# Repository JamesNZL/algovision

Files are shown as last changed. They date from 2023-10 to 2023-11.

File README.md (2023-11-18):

<div align="center">
   
</div>

# algovision

<div align="center">
   <br>
   <div>
      <a href="https://github.com/JamesNZL/algovision/issues">
         
      </a>
      <a href="https://github.com/JamesNZL/algovision/pulls">
         
      </a>
      <!-- <a href="https://github.com/JamesNZL/algovision/actions/workflows/release.yml">
         <img src="https://img.shields.io/github/actions/workflow/status/jamesnzl/algovision/release.yml?branch=main" alt="GitHub workflow status">
      </a> -->
      <a href="https://github.com/JamesNZL/algovision/commits">
         
      </a>
   </div>
   <br>
</div>

A self-driven project to design an algorithm visualisation tool with a union of hardware and firmware.

## Project Documentation

> [!important]
> Visit the [GitHub Pages deployment](https://docs.jamesnzl.xyz/algovision) to view the documentation for this project.

## Software Used

| Package | Used for |
| --- | --- |
| Obsidian | The scratch pad for documentation and design. |
| Concepts | The rough sketches and ideation. |
| Visual Studio Code | The text editing and firmware development. |
| LTspice | The hardware simulation and verification. |
| Altium Designer | The schematic capture and PCB artwork. |
| SOLIDWORKS | The 3D models of components. |
| Figma | The iterative matrix mockups and topology design. |
| Adobe Illustrator  | The algovision logo. |

# Licence

The [`Karbon`](https://klim.co.nz/retail-fonts/karbon/) font family is licensed for perpetual use within this project under the terms of the [Klim Desktop Font Licence Agreement](https://klim.co.nz/licences/desktop-fonts/).

The hardware design files in this repository are licensed under the `CERN Open Hardware Licence Version 2 - Permissive`, and source code is licensed under `MIT`.

See [`LICENSE.md`](./LICENSE.md) for full details.

Learn more about [open-source hardware](https://www.oshwa.org/faq/).

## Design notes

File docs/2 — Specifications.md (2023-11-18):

#5e5ce6/projects 

# Specifications

> [!NOTE]  
> This document lists the specifications that the outcome must satisfy.

---

1. The outcome must be portable, and no larger than an iPad mini 6 ($195.43\,\text{mm} \times 134.75\,\text{mm}$, $12.88\,\text{mm}$ corner radius, [reference](https://developer.apple.com/accessories/Accessory-Design-Guidelines.pdf#page=284)).

2. The outcome must be reasonably priced—I don't mind putting a bit of money into it, and the focus is not on making something commercially viable—but it should be realistic.

3. The outcome must be aesthetically pleasing.

4. The outcome must be [[power]] efficient and [[Batteries|battery]] powered.

5. The outcome must be capable of an [[Auto-Shutdown|auto-sleep/shutdown]] if left unattended.

6. The outcome must be easily programmed using a [[USB Type-C Connectors|USB Type-C connector]].

7. The outcome must be effective towards its goal of aiding in the visualisation of different [[sorting]] and [[pathfinding]]/[[search]] [[algorithms]].

8. The outcome must be self-contained, and must not be reliant on any extraneous supplies/loads/test environments/etc.

9. The outcome must have [[Scopes/Interface/Operating Modes|operating modes]] to either single-step through an algorithm, or automatically execute at a configurable rate.

10. The outcome must have [[Scopes/Power/Power Indicator|power indicator]] LEDs to notify the user when the batteries have [[Scopes/Power/Battery Voltage Sensing|discharged too far]].

11. The outcome must include [[Scopes/Interface/Debug LEDs|debug]] pins/test points and LEDs to facilitate effective development and debugging.

12. The outcome should be easy to operate, with minimal [[Interface|end-user input]] required.

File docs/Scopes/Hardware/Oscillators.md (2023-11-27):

#5e5ce6/projects 

# Oscillators

I will need to select two oscillators in this project:

1. [[TLC5951DAP]] [[LED Drivers|LED Driver]] greyscale clock, and
2. [[STM32U575CIT6Q]] `HSE` clock.

## Greyscale Clock

I calculated in [[Minimum Data Frequency]] that my greyscale reference clock should be at least $5.16\,\text{MHz}$ for the full 12-bit resolution [[Pixel Brightness]] control.

I also know that the [[TLC5951DAP]] can accept a maximum greyscale clock frequency of $33\,\text{MHz}$, and, owing to the [[Auto Display Repeat]] functionality, I will aim to select a clock frequency nearer to the upper-end of this, for greater granularity/smooth persistence-of-vision in my LED pixel brightnesses.

I will select an oscillator by primarily considering cost, stock, temperature stability, accuracy, power consumption, and jitter, and just making sure that the selected oscillator has a frequency $5.2\,\text{MHz} \ll f_\text{osc} < 33\,\text{MHz}$.

Performing a parametric search on DigiKey, to filter for only part numbers that are:
1. surface mount,
2. in stock,
3. active product status, and
4. have a datasheet,
I narrow down the product selection from over 440 thousand to 171 thousand.

I see that I have an option between crystal-type oscillators and MEMS-type oscillators,

### Microcontroller `HSE` Clock

For my microcontroller `HSE` clock, I will simply re-use the same $32\,\text{MHz}$ oscillator that I selected for my greyscale clock above, for purposes of BOM consolidation. This selected oscillator is equally fit-for-purpose for this application, for the reasons discussed in [[Microcontroller#`HSE` Clock]].

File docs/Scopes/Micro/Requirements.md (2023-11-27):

#5e5ce6/projects 

# Requirements

## Peripherals

### RAM

To get a ball-park estimate, I will consider just my [[Frame Buffers]]—assuming that I have two rotating frame buffers for my [[Display]], this gives me a minimum of $8.7\,\text{kiB}$ of RAM required.

### Timers

I will need a timer for:

1. Row control [[Shift Registers]] timing
2. ~~Column control [[LED Drivers]] greyscale reference clock~~
	> I will actually provide this with a dedicated [[Oscillators]] to reduce the workload of my [[Microcontroller]], and reduce the routing of high-speed signal traces.

As per my [[Minimum Data Frequency]] calculations, I must clock my shift registers at least at $1260\,\text{Hz}$, or a period of $0.8\,\text{ms}$. This will be easily achievable with a 8- or 16-bit timer with a clock prescaler applied to the system clock.

### SPI

For my [[Display]], I must select a microcontroller that is capable of transferring serial data to my [[LED Drivers]] at the required [[Minimum Data Frequency]] of at least $f_\text{clk, SPI} > 18.2\,\text{MHz}$.

I note that this is separate from the microcontroller's operating frequency; as there is no inherent synchronisation between the [[Frame Buffers]] and the matrix timing constraints—as long as I can shift the data out from the read-only frame buffer in time with enough left-over instructions to slowly compute the contents of the write-only frame buffer, everything should be fine.

### GPIO

| Purpose | Pins Required | Remarks |
| --- | --- | --- |
| [[Display]] row control | 3 | Shift register clear, clock, serial input |
| [[Display]] column control | 8 | LED driver `GSSIN`, `DCSIN`, `GSSCK`, `GSLAT`, `DCSCK`, `~XBLNK`, `GSCK`, flags input |
| [[Debug LEDs]] | 4+ | Heartbeat LED, status, `TX`, `RX`—assuming a single GPIO per LED |
| [[User Pushbuttons]] | 1+ | |
| [[Brightness Control]] | 1+ | |

For my [[Display|display]] [[Shift Registers|shift register]] row control, I intend on bit-banging the serial output using a GPIO pin and a timer interrupt. For my [[LED Drivers|LED driver]] column control however, I intend on using a serial SPI peripheral to transfer the data, and a separate timer interrupt for the greyscale reference clock pin.

This gives a total minimum of 17 available GPIO pins.

### ADC

At minimum, I will need one channel for my [[Brightness Control]] knob, and another channel for my [[Current Sensing]] signal.

### USB-UART

I would prefer to have a microcontroller that can be directly [[Programming|programmed]] with a [[USB Type-C Connectors|USB-C]] connection, without requiring an external [[Scopes/Micro/USB to Serial|USB-to-serial]] chip.

This will require further research to see whether this would still allow a debugger to be attached, though.

### Watchdog Timer

I will need at least one [[Watchdog Timer]]. Preferably, this will be a window watchdog—I can then perhaps configure it to require a refresh within a window around my row-refresh timing, to help ensure that my display is being driven with correct timing.

### USB PD PHY

It would be desirable to have in-built [[USB Power Delivery]] [[USB-C Configuration Controller]] or [[USB Power Delivery Control Peripheral]], such that I do not require an external USB-C/PD controller IC.

### Connectivity

I would like to have the option to implement wireless Bluetooth Low Energy/WiFi [[Connectivity|connectivity]] in the future.

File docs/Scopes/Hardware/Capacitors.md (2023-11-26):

#5e5ce6/projects 

# Capacitors

I will approach my capacitor selection similarly as to that for my [[Resistors]]—I will use a DigiKey parametric search.

I know that the primary application in this project will be for decoupling capacitors, and not much filtering/analogue. Consequently, I expect that my requirements are fairly relaxed, as I do not require extreme tolerances/stability/accuracy.

I would also expect the operating profile to be fairly low-calibre, as I do not expect this board to be used in extreme temperatures or otherwise demanding environments. With that said however, I will likely still need to consider operating temperatures due to the power dissipation of the components on the board.

With this considerations in mind, I will primarily focus on Class II MLCC capacitors, and specifically `X7R` type MLCCs. Due to the nature of my application, I will need to carefully consider capacitance degradation with respect to the applied DC bias voltage. For any filters/oscillator load capacitances, I will look at Class I `C0G` or `NP0` capacitors for their constant DC voltage and temperature response.

Unlike my search for [[Resistors]] however, in this case I will place less direct emphasis on a specific family of devices, in order to facilitate more application-specific decisions.

Applying a basic search filter to only parts that are:
1. surface mount,
2. in stock,
3. available as Cut Tape,
4. active product status, and
5. have a datasheet,
I narrow down the product selection from over 800 thousand to 36 thousand.

Sorting by stock quantity in descending order, I see that the most stocked manufacturers are:
- Murata
- Samsung
- YAGEO
- KYOCERA AVX
- Walsin

I see that the YAGEO [Commodity Multilayer Ceramic Capacitor](https://www.digikey.co.nz/en/product-highlight/y/yageo/commodity-multilayer-ceramic-capacitors-cc-series) series includes `NP0`, `X7R`, `X5R`, and `Y5V` type capacitors, such that I may just be able to stay within this one family. For purely aesthetic reasons, I also note that these YAGEO capacitors are the only black/grey devices compared to the typical brown/orange of the other manufacturers, which may look better on my black [[PCB]], and also means that I can have all my resistors/capacitors from one manufacturer.

Looking at Samsung's line of [MLCCs](https://www.digikey.co.nz/en/product-highlight/s/samsung-electromech/multi-layer-ceramic-capacitors), I see that this series only includes Class II type capacitors, and no Class I offerings—unlike the YAGEO series—but *does* include capacitances up to $200\,\micro\text{F}$, unlike the maximum capacitance of $100\,\micro\,\text{F}$ from YAGEO—but I do not expect this to be a problem as I do not expect to need capacitances this high (at least from an MLCC).

> [!success] Preferred Series
> I will use devices from the YAGEO [`CC`](https://www.yageo.com/en/Product/Index/mlcc) general purpose multi-layer ceramic capacitor series.

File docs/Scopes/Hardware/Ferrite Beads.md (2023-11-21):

#5e5ce6/projects 

# Ferrite Beads

As I have not used ferrite beads before, I want to first understand how to use them properly & select an appropriate part.

## Theoretical Analysis

I will begin by using [[LTspice]] to analyse an equivalent model.

![[Pasted image 20231120171100.png]]

I see that the ferrite bead acts as type of band-reject filter, where it attenuates high-frequency signals until the reactance of the parallel capacitor dominates and begins to act as a short circuit.

### Impedance Transfer Function

I will first derive the transfer function for the impedance of the equivalent model in the $s$ domain, to help myself visualise the frequency response of the ferrite bead.

#### Analytical

![[Pasted image 20231120173120.png]]

Taking the circuit into the Laplace domain, I see that I simply have three impedances in parallel, in series with $R_\text{s}$. The equivalent impedance is therefore derived as (assuming steady-state, ie zero initial conditions)
$$
\begin{align}
Z & = R_\text{s} + \left(\frac{1}{sC_\text{par}} \parallel sL_\text{bead} \parallel R_\text{AC}\right) \\[0.75em]
 & = R_\text{s} + \left( \frac{1}{sC_\text{par} + \frac{1}{sL_\text{bead}} + \frac{1}{R_\text{AC}} }\right) \\[0.75em]
 & = R_\text{s} + \left( \frac{sL_\text{bead}R_\text{AC}}{ s^2C_\text{par}L_\text{bead}R_\text{AC} + R_\text{AC} + sL_\text{bead} } \right) \\[0.75em]
 & = R_\text{s} + \frac{sL_\text{bead}R_\text{AC}}{s^2\left(C_\text{par}L_\text{bead}R_\text{AC}\right) + sL_\text{bead} + R_\text{AC}}
\end{align}
$$

Letting $s=j\omega$, I find
$$
\begin{align}
Z &= R_\text{s} + \frac{j\omega L_\text{bead}R_\text{AC}}{j^2\omega^2\left(C_\text{par}L_\text{bead}R_\text{AC}\right) + j\omega L_\text{bead} + R_\text{AC}} \\[0.75em]
&= R_\text{s}+\frac{j\omega L_\text{bead}R_\text{AC}}{-\omega^2\left(C_\text{par}L_\text{bead}R_\text{AC}\right) + j\omega L_\text{bead} + R_\text{AC}} \\[0.75em]
&= R_\text{s} + \frac{j\omega L_\text{bead}R_\text{AC}}{\left(R_\text{AC} - \omega^2C_\text{par}L_\text{bead}R_\text{AC}\right) + j\left(\omega L_\text{bead}\right)}\\[0.75em]
\end{align}
$$

Let $D$ be the denominator term, that is
$$
D = \left(R_\text{AC} - \omega^2C_\text{par}L_\text{bead}R_\text{AC}\right) + j\left(\omega L_\text{bead}\right)

$$

Combining the two terms into a single fraction, I have
$$
\begin{align}
Z &= \frac{R_\text{s}D}{D} + \frac{j\left(\omega L_\text{bead}R_\text{AC}\right)}{D}\\[0.75em]
&= \frac{R_\text{s}D + j\left(\omega L_\text{bead}R_\text{AC}\right)}{D} \\[0.75em]
&= \frac{R_\text{s}D + j\left(\omega L_\text{bead}R_\text{AC}\right)}{\left(R_\text{AC} - \omega^2C_\text{par}L_\text{bead}R_\text{AC}\right) + j\left(\omega L_\text{bead}\right)} \\[0.75em]
\end{align}
$$

Multiplying by the conjugate of the denominator $D$, ie $\overline{D}$, I have
$$
\begin{align}
Z &= \frac{R_\text{s}D + j\left(\omega L_\text{bead}R_\text{AC}\right) }{\left(R_\text{AC} - \omega^2C_\text{par}L_\text{bead}R_\text{AC}\right) + j\left(\omega L_\text{bead}\right)} \times \frac{\left(R_\text{AC} - \omega^2C_\text{par}L_\text{bead}R_\text{AC}\right) - j\left(\omega L_\text{bead}\right)}{\left(R_\text{AC} - \omega^2C_\text{par}L_\text{bead}R_\text{AC}\right) - j\left(\omega L_\text{bead}\right)}\\[0.75em]
&= \frac{\Bigl(R_\text{s}D + j\left(\omega L_\text{bead}R_\text{AC}\right) \Bigr) \Bigl(\left(R_\text{AC} - \omega^2C_\text{par}L_\text{bead}R_\text{AC}\right) - j\left(\omega L_\text{bead}\right)\Bigr)}{\left(R_\text{AC} - \omega^2C_\text{par}L_\text{bead}R_\text{AC}\right)^2 - j^2\left(\omega L_\text{bead}\right)^2} \\[0.75em]
&= \frac{   \Bigl(R_\text{s}R_\text{AC}D-\omega^2C_\text{par}L_\text{bead}R_\text{s}R_\text{AC}D-j\left(\omega L_\text{bead}R_\text{s}D\right)\Bigr)    +    \Bigl( j\left(\omega L_\text{bead}R_\text{AC}^2\right) - j\left( \omega^3C_\text{par}L_\text{bead}^2R_\text{AC}^2 \right)  - j^2\left( \omega^2L_\text{bead}^2R_\text{AC} \right)  \Bigr)     }{\left(R_\text{AC}^2 - 2\omega^2C_\text{par}L_\text{bead}R_\text{AC}^2+\omega^4C_\text{par}^2L_\text{bead}^2R_\text{AC}^2\right) + \left(\omega^2 L_\text{bead}^2\right)} \\[0.75em]
&= \frac{   R_\text{s}R_\text{AC}D-\omega^2C_\text{par}L_\text{bead}R_\text{s}R_\text{AC}D-j\left(\omega L_\text{bead}R_\text{s}D\right)    +    j\left(\omega L_\text{bead}R_\text{AC}^2\right) - j\left( \omega^3C_\text{par}L_\text{bead}^2R_\text{AC}^2 \right)  + \left( \omega^2L_\text{bead}^2R_\text{AC} \right)  }{\left(R_\text{AC}^2 - 2\omega^2C_\text{par}L_\text{bead}R_\text{AC}^2+\omega^4C_\text{par}^2L_\text{bead}^2R_\text{AC}^2\right) + \left(\omega^2 L_\text{bead}^2\right)} \\[0.75em]
&= \frac{  \Bigl(  \omega^2L_\text{bead}^2R_\text{AC} + R_\text{s}R_\text{AC}D-\omega^2C_\text{par}L_\text{bead}R_\text{s}R_\text{AC}D    \Bigr)    +   j\Bigl(       \omega L_\text{bead}R_\text{AC}^2  -\omega L_\text{bead}R_\text{s}D     -\omega^3C_\text{par}L_\text{bead}^2R_\text{AC}^2  \Bigr)   }{    \omega^4C_\text{par}^2L_\text{bead}^2R_\text{AC}^2 + \omega^2 L_\text{bead}^2 + R_\text{AC}^2 - 2\omega^2C_\text{par}L_\text{bead}R_\text{AC}^2    }
\end{align}
$$

Substituting $D$ back in, I get
$$
\begin{align}

Z &= \frac{  \Bigl(  \omega^2L_\text{bead}^2R_\text{AC} + R_\text{s}R_\text{AC}\Bigl(\left(R_\text{AC}-\omega^2C_\text{par}L_\text{bead}R_\text{AC}\right)+j\left(\omega L_\text{bead}\right)\Bigr)-\omega^2C_\text{par}L_\text{bead}R_\text{s}R_\text{AC}\Bigl(\left(R_\text{AC}-\omega^2C_\text{par}L_\text{bead}R_\text{AC}\right)+j\left(\omega L_\text{bead}\right)\Bigr)    \Bigr)    +   j\Bigl(       \omega L_\text{bead}R_\text{AC}^2  -\omega L_\text{bead}R_\text{s}\Bigl(\left(R_\text{AC}-\omega^2C_\text{par}L_\text{bead}R_\text{AC}\right)+j\left(\omega L_\text{bead}\right)\Bigr)     -\omega^3C_\text{par}L_\text{bead}^2R_\text{AC}^2  \Bigr)   }{    \omega^4C_\text{par}^2L_\text{bead}^2R_\text{AC}^2 + \omega^2 L_\text{bead}^2 + R_\text{AC}^2 - 2\omega^2C_\text{par}L_\text{bead}R_\text{AC}^2    } \\[0.75em]

&= \frac{  \Bigl(  \omega^2L_\text{bead}^2R_\text{AC} + R_\text{s}R_\text{AC}^2-\omega^2C_\text{par}L_\text{bead}R_\text{s}R_\text{AC}^2+j\left(\omega L_\text{bead}R_\text{s}R_\text{AC}\right)-\omega^2C_\text{par}L_\text{bead}R_\text{s}R_\text{AC}^2 + \omega^4C_\text{par}^2L_\text{bead}^2R_\text{s}R_\text{AC}^2-j\left(\omega^3C_\text{par} L_\text{bead}^2R_\text{s}R_\text{AC}\right)  \Bigr)  +   j\Bigl(       \omega L_\text{bead}R_\text{AC}^2  -\omega L_\text{bead}R_\text{s}      R_\text{AC}+\omega^3C_\text{par}L_\text{bead}^2R_\text{s}R_\text{AC}-j\left(\omega^2 L_\text{bead}^2R_\text{s}\right)     -\omega^3C_\text{par}L_\text{bead}^2R_\text{AC}^2  \Bigr)   }{    \omega^4C_\text{par}^2L_\text{bead}^2R_\text{AC}^2 + \omega^2 L_\text{bead}^2 + R_\text{AC}^2 - 2\omega^2C_\text{par}L_\text{bead}R_\text{AC}^2    } \\[0.75em]

&= \frac{  \Bigl(  \omega^2L_\text{bead}^2R_\text{AC} + R_\text{s}R_\text{AC}^2-\omega^2C_\text{par}L_\text{bead}R_\text{s}R_\text{AC}^2-\omega^2C_\text{par}L_\text{bead}R_\text{s}R_\text{AC}^2 + \omega^4C_\text{par}^2L_\text{bead}^2R_\text{s}R_\text{AC}^2  \Bigr) +   j\Bigl(       \omega L_\text{bead}R_\text{AC}^2 +\omega L_\text{bead}R_\text{s}R_\text{AC} -\omega L_\text{bead}R_\text{s}      R_\text{AC}+\omega^3C_\text{par}L_\text{bead}^2R_\text{s}R_\text{AC}  - \omega^3C_\text{par} L_\text{bead}^2R_\text{s}R_\text{AC}   -\omega^3C_\text{par}L_\text{bead}^2R_\text{AC}^2  \Bigr)  -j^2\left(\omega^2 L_\text{bead}^2R_\text{s}\right) }{    \omega^4C_\text{par}^2L_\text{bead}^2R_\text{AC}^2 + \omega^2 L_\text{bead}^2 + R_\text{AC}^2 - 2\omega^2C_\text{par}L_\text{bead}R_\text{AC}^2    } \\[0.75em]

&= \frac{  \Bigl(  \omega^2L_\text{bead}^2R_\text{AC} +\omega^2 L_\text{bead}^2R_\text{s} + R_\text{s}R_\text{AC}^2-\omega^2C_\text{par}L_\text{bead}R_\text{s}R_\text{AC}^2-\omega^2C_\text{par}L_\text{bead}R_\text{s}R_\text{AC}^2 + \omega^4C_\text{par}^2L_\text{bead}^2R_\text{s}R_\text{AC}^2  \Bigr) +   j\Bigl(       \omega L_\text{bead}R_\text{AC}^2 +\omega L_\text{bead}R_\text{s}R_\text{AC} -\omega L_\text{bead}R_\text{s}      R_\text{AC}+\omega^3C_\text{par}L_\text{bead}^2R_\text{s}R_\text{AC}  - \omega^3C_\text{par} L_\text{bead}^2R_\text{s}R_\text{AC}   -\omega^3C_\text{par}L_\text{bead}^2R_\text{AC}^2  \Bigr)   }{    \omega^4C_\text{par}^2L_\text{bead}^2R_\text{AC}^2 + \omega^2 L_\text{bead}^2  + R_\text{AC}^2 - 2\omega^2C_\text{par}L_\text{bead}R_\text{AC}^2    }

\end{align}
$$

Collecting like terms and simplifying, I have
$$
\begin{align}

Z &= \frac{  \Bigl(  \omega^4C_\text{par}^2L_\text{bead}^2R_\text{s}R_\text{AC}^2  + \omega^2L_\text{bead}^2R_\text{AC} +\omega^2 L_\text{bead}^2R_\text{s} + R_\text{s}R_\text{AC}^2-2\omega^2C_\text{par}L_\text{bead}R_\text{s}R_\text{AC}^2  \Bigr) +   j\Bigl(       \omega L_\text{bead}R_\text{AC}^2  -\omega^3C_\text{par}L_\text{bead}^2R_\text{AC}^2  \Bigr)   }{    \omega^4C_\text{par}^2L_\text{bead}^2R_\text{AC}^2 + \omega^2 L_\text{bead}^2 + R_\text{AC}^2 - 2\omega^2C_\text{par}L_\text{bead}R_\text{AC}^2    } \\[0.75em]

&= \frac{  \omega^4\left(C_\text{par}^2L_\text{bead}^2R_\text{s}R_\text{AC}^2\right)  + \omega^2\Bigl(L_\text{bead}^2\left(R_\text{AC} + R_\text{s}\right) - 2C_\text{par}L_\text{bead}R_\text{s}R_\text{AC}^2 \Bigr) + R_\text{s}R_\text{AC}^2    }{    \omega^4\left(C_\text{par}^2L_\text{bead}^2R_\text{AC}^2\right) + \omega^2\left( L_\text{bead}^2 - 2C_\text{par}L_\text{bead}R_\text{AC}^2 \right)   + R_\text{AC}^2   }  + \frac{ j\Bigl(       \omega L_\text{bead}R_\text{AC}^2  -\omega^3C_\text{par}L_\text{bead}^2R_\text{AC}^2  \Bigr) }{    \omega^4\left(C_\text{par}^2L_\text{bead}^2R_\text{AC}^2\right) + \omega^2\left( L_\text{bead}^2 - 2C_\text{par}L_\text{bead}R_\text{AC}^2 \right)   + R_\text{AC}^2   } \\[0.75em]

\end{align}
$$

![[Pasted image 20231121153742.png]]

Figure 2 of Analog Dialogue 50-02

Plotting the magnitude response in [Desmos](https://www.desmos.com/calculator/2eojibsjul), I see a plot that is very similar to `Figure 2` of [Analog Dialogue 50-02](https://www.analog.com/media/en/analog-dialogue/volume-50/number-1/articles/ferrite-beads-demystified.pdf), which is quite encouraging. I do see that although exact values are wrong (the $y$-axis value is off by *many* orders of magnitude), the general shape of the response is correct. Interestingly, if I reduce the order of the $-\omega^3$ term in the imaginary term to $-\omega^2$, the plot becomes *much* closer to the 'expected' value, as seen in the screenshot below.

![[Pasted image 20231121153827.png]]

I am not fully certain whether this is an algebraic error in my working, or what else it may be—but I do not think it is valuable to spend too much time on this topic.

> [!summary]
> I see in this plot (where the $x$-axis is frequency, in $\text{MHz}$) that the ferrite bead presents a very low impedance at low frequencies, whilst the inductive reactance dominates. As the frequency increases, I see a resonant peak where the $R_\text{AC}$ resistive component dominates, where the ferrite bead impedance increases significantly—which would lead to a larger voltage drop and power dissipated across the ferrite bead as heat energy. As the frequency continues to increase further however, the capacitive reactance dominates, such that the ferrite bead returns to presenting a low impedance.
> 
> Again, I see the band-reject characteristic of the ferrite bead.

#### MATLAB

```matlab
%%% FerriteImpedance.m
% A MATLAB script to model the impedance response of a ferrite bead.
%
% Author: James Bao

%% Sanitise Workspace
clear;
close all;
clc;

fprintf("FerriteBead.m\n\n");

%% Model Parameters

% Series Resistance
Rs = 0.3;

% Parasitic Capacitance
Cpar = 1.678e-12;

% Bead Inductance
Lbead = 1.208e-6;

% AC Resistance
Rac = 1.082e3;

%% Transfer Function

X_Cpar = tf(1, [Cpar 0]);
X_Lbead = tf([Lbead 0], 1);

Z = Rs + (1 / ((1/X_Cpar) + (1/X_Lbead) + (1/Rac)));

%% Plot Frequency Response

[mag, phase, w] = bode(Z, {0.1e6, 100e9});

w = w / (2 * pi * 1e6); % Convert w to f

semilogx(w, squeeze(mag));

xlabel('Frequency (MHz)', 'FontSize', 24);
ylabel('Impedance (Ohms)', 'FontSize', 24);
title('Impedance Response of Ferrite Bead Model', 'FontSize', 28);
```

![[Pasted image 20231121153407.png]]

Using [[MATLAB]] to plot the impedance response of my ferrite bead model with respect to frequency in order to validate my [[Ferrite Beads#Analytical|analytical]] working, I see that I reproduce the exact plot seen in the [Analog Dialogue 50-02](https://www.analog.com/media/en/analog-dialogue/volume-50/number-1/articles/ferrite-beads-demystified.pdf) article, and very similar to my Desmos plots.

### Frequency Response

#### Inductance

![[Pasted image 20231120171814.png]]

![[Pasted image 20231121014847.png]]

I see that increasing the inductance will pull the crossover frequency lower, whilst decreasing it will push it higher.

#### Capacitance

![[Pasted image 20231121014944.png]]

![[Pasted image 20231121014954.png]]

I see identical behaviour when changing the capacitance; the crossover frequency is inversely proportional to the parasitic capacitance $C_\text{par}$.

#### Resistance

![[Pasted image 20231121015122.png]]

![[Pasted image 20231121015132.png]]

Finally, I see that the AC loss resistance $R_\text{AC}$ does not have an effect on the crossover frequency, but does affect the amount of attenuation within the rejection band. This is as I would expect, as I would expect the crossover frequency to be dependent only on the reactive elements—whilst $R_\text{AC}$ captures the impedance presented to signals within the reject-band—and consequently the voltage drop & power dissipated.

![[Pasted image 20231121015443.png]]

![[Pasted image 20231121015458.png]]

Finally, I see a similar scaling behaviour when changing the series resistor $R_\text{s}$, but this is applied to the entire response, rather than just within the rejection band. This is again as I would expect, as this series resistor cannot be reduced by a parallel reactive element; it always contributes to the total impedance regardless of frequency.

### $LC$ Filter

#### Undamped

![[Pasted image 20231121132001.png]]

Modelling a simple $LC$ filter network in [[LTspice]] with a somewhat arbitrarily selected ferrite bead connected to my [[Microcontroller#Decoupling]] capacitors, I see a frequency response with a significant resonant peak at $\approx 47\,\text{kHz}$. This immediately tells me to expect a significant overshoot/ringing when looking at the time-domain step response of this filter, such as if there were to be some switching noise at the input.

![[Pasted image 20231121131701.png]]

![[Pasted image 20231121132933.png]]

Adjusting the source to model some (very arbitrary, and very exaggerated) switching noise and performing a transient analysis, I see exactly that ringing at the output of my filter.

Simplifying the ferrite bead to be a pure inductor of reactance $sL$, I can derive the transfer function of the filter to be a simple impedance divider with gain
$$
\begin{align}
G=\frac{V_\text{o}}{V_\text{s}}&=\frac{\frac{1}{sC}}{\frac{1}{sC}+sL}\\[0.75em]
&= \frac{1}{1+s^sLC}
\end{align}
$$

Considering the general form of a second-order transfer function
$$
G(s)=\frac{\omega_\text{n}^2}{s^2+2\zeta\omega_\text{n}s+\omega_\text{n}^2}=\frac{1}{1+(\frac{2\zeta}{\omega_\text{n}})s+(\frac{1}{\omega_\text{n}^2})s^2}
$$
I immediately see that I have a system with a natural frequency $w_\text{n}$ where
$$
\omega_\text{n}=\sqrt{\frac{1}{LC}}
$$
and a damping ratio $\zeta$
$$
\zeta=0
$$

This tells me that this models an undamped system, which helps to explain why I see so much oscillation. Of course, I see that the real system is, in fact, damped, but I still see value in this idealised understanding. As explained in the Analog Dialogue article, this is because the resistive component $R_\text{AC}$ does not become significant until a certain frequency, below which the ferrite bead does indeed behave as an ideal inductor.

This also tells me that the resonant frequency occurs at the natural frequency $\omega_\text{n}$, that is
$$
\begin{align}
\omega &= 2\pi f \\[0.75em]
f_\text{resonance} &= \frac{\sqrt{\frac{1}{LC}}}{2\pi}
\end{align}
$$
Applying this to my model, I calculate a resonant frequency $f_\text{resonance}=43\,\text{kHz}$—which is very close to the observed resonant frequency in my simulations. I would indeed expect a slight deviation due to the inaccuracies of my idealised model.

#### Damped

I know from control theory that, in order to reduce the magnitude of the resonant peak in the frequency domain, I must increase the damping ratio $\zeta$. I can do this by inserting an additional resistive element to dissipate energy, which I will add in series with the inductor.

This gives me a new gain $G'$
$$
\begin{align}
G'&=\frac{\frac{1}{sC}}{\frac{1}{sC}+\left(sL+R\right)} \\[0.75em]
&=\frac{1}{1+s^2LC+sCR}
\end{align}
$$

I see that I now have a damping ratio given by
$$
\begin{align}
\frac{2\zeta}{\omega_\text{n}}&=CR\\[0.75em]
\zeta &= \frac{CR\sqrt{\frac{1}{LC}}}{2}
\end{align}
$$
such that
$$
\zeta \propto R
$$

Therefore, for my original circuit with parameters
$$
\begin{align}
L &= 12.4\,\micro\text{H} \\[0.75em]
C &= 1.1\,\micro\text{F} \\[0.75em]
\end{align}
$$
and a desired damping ratio
$$
\zeta = 0.7
$$
I compute a necessary resistance
$$
\begin{align}
R &= \frac{2\zeta}{C\sqrt{\frac{1}{LC}}} \\[0.75em]
& = 4.7\,\Omega
\end{align}
$$

![[Pasted image 20231121174348.png]]

![[Pasted image 20231121174420.png]]

Simulating the response of this damped $RLC$ filter in [[LTspice]], I indeed see that the resonant peak and ringing has been eliminated, and the overshoot significantly reduced. Great!

#### Cut-Off Frequency

I do however still see that the switching noise is still present—this tells me that the roll-off frequency of my filter is too high, and is not attenuating the frequencies of interest. I know that my arbitrary, artificial switching pulse has an on-time of $100\,\micro\text{s}$ with edges of $10\,\text{ns}$. I will first try to filter out the fundamental frequency of
$$
\begin{align}
f_\text{fundamental} &= \frac{1}{2\times 100\,\micro\text{s}} \\[0.75em]
& = 5\,\text{kHz}
\end{align}
$$

I will therefore try to place my new roll-off frequency $f_\text{roll-off}'$ one decade lower than this, that is
$$
\begin{align}
f_\text{roll-off}' = f_\text{resonance} & = \frac{\sqrt{\frac{1}{LC'}}}{2\pi} \\[0.75em]
& =1\,\text{kHz} 
\end{align}
$$
Assuming a fixed inductor value, I will derive an expression for the new capacitance $C'$ as
$$
\begin{align}
C'&= \frac{1}{L\left(2\pi f_\text{roll-off}'\right)^2} \\[0.75em]
& = 2.04\,\text{mF}
\end{align}
$$
and a new damping resistor
$$
R'=109\,\text{m}\Omega
$$

Although these component values (ie $C'$) are not necessarily realistic (stemming from the arbitrary simulation setup), I am mostly interested in learning the process and developing an intuition around such resonant systems, and particularly the importance of damping elements—as I have not really had to deal with this before.

![[Pasted image 20231121174703.png]]

![[Pasted image 20231121174609.png]]

I see that these new $C'$ and $R'$ values do indeed pull the roll-off frequency to the left, and lead to an *much* cleaner transient response.

#### Conclusions

> [!summary]
> From this exploration, I have learnt:
> - The $LC$ filter formed with a ferrite bead and capacitor produces a low-pass characteristic
> - Without sufficient damping, the filter can exhibit a resonant peak and cause significant ringing
> - The cut-off frequency must be carefully chosen to actually attenuate the high-frequency noise of interest, where the cut-off frequency is dependent on the ferrite bead

![[Pasted image 20231121191229.png]]

I see that, if I choose to implement a ferrite bead in my design, I should make sure to fit a DNP zero-ohm jumper across the ferrite bead (and potentially the damping resistor, depending on its magnitude), in case I find that it actually negatively impacts the circuit. This will produce a simple first-order $RC$ low-pass filter with a reduced $-20\,\text{dB/dec}$ roll-off, but no risk of resonance.

## Implementation

### References

- [Ferrite Beads Demystified | Analog Devices](https://www.analog.com/en/analog-dialogue/articles/ferrite-beads-demystified.html)
- [How Do Ferrite Beads Work and How Do You Choose the Right One? | PCB Design Blog | Altium](https://resources.altium.com/p/how-do-ferrite-beads-work-and-how-do-you-choose-right-one)
- [Everything You Need to Know About Ferrite Beads | Altium](https://resources.altium.com/p/everything-you-need-to-know-about-ferrite-beads)

> [!note]
> A *great* video about using an $LC$ filter network on an analogue supply pin—[Shall We Use a Ferrite Bead in Power Rail or Not? | Explained by Eric Bogatin - YouTube](https://www.youtube.com/watch?v=HaLMjVkKYMw)

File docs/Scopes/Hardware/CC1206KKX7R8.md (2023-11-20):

#5e5ce6/projects 

# `CC1206KKX7R8`

> [!success] Preferred Series
> I will use devices from the YAGEO [`CC`](https://www.yageo.com/en/Product/Index/mlcc) general purpose multi-layer ceramic capacitor series.
> 
> Refer to [[Capacitors]] for full details.

| Part Number | `CC1206KKX7R8` |
| --- | --- |
| Image |  |
| Supplier Link  | [DigiKey](https://www.digikey.co.nz/short/997dt5n8) |
| Datasheet | [Datasheet](https://www.yageo.com/upload/media/product/productsearch/datasheet/mlcc/UPY-GPHC_X7R_6.3V-to-250V_23.pdf) |
| Terminals | 2 |
| Voltage Rating | $25\,\text{V}$ |
| Tolerance | $\pm 10\%$ |
| Type | `X7R` |
| Package | `1206` |

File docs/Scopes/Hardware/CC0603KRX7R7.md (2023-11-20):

#5e5ce6/projects 

# `CC0603KRX7R7`

> [!success] Preferred Series
> I will use devices from the YAGEO [`CC`](https://www.yageo.com/en/Product/Index/mlcc) general purpose multi-layer ceramic capacitor series.
> 
> Refer to [[Capacitors]] for full details.

| Part Number | `CC0603KRX7R7` |
| --- | --- |
| Image |  |
| Supplier Link  | [DigiKey](https://www.digikey.co.nz/short/997dt5n8) |
| Datasheet | [Datasheet](https://www.yageo.com/upload/media/product/productsearch/datasheet/mlcc/UPY-GPHC_X7R_6.3V-to-250V_23.pdf) |
| Terminals | 2 |
| Voltage Rating | $16\,\text{V}$ | 
| Tolerance | $\pm 10\%$
| Type | `X7R` |
| Package | `0603` |

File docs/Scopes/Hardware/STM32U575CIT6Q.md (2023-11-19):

#5e5ce6/projects 

# `STM32U575CIT6Q`

> [!success] Selected Device
> Following a thorough selection process as documented in [[STM32#Product Selector]], I have decided to proceed with the [`STM32U575CIT6Q`](https://www.digikey.co.nz/en/products/detail/stmicroelectronics/STM32U575CIT6Q/18085454).
> 
> Refer to [[STM32]] for full details.

| Part Number | `STM32U575CIT6Q` |
| --- | --- |
| Image |  |
| Supplier Link | [DigiKey](https://www.digikey.co.nz/en/products/detail/stmicroelectronics/STM32U575CIT6Q/18085454) |
| Datasheet | [Datasheet](https://www.st.com/resource/en/datasheet/stm32u575ag.pdf) |
| Package | `48-LQFP` |
| Pin Pitch | $0.5\,\text{mm}$ |
| Processor | Cortex-M33 |
| Voltage | $1.71\sim3.6\,\text{V}$ |
| Operating Frequency | $160\,\text{MHz}$ |
| Core Width | 32-bit |
| I/O Pins | 33 |
| Flash | $2048\,\text{kiB}$ |
| RAM | $786\,\text{kiB}$ |
| Cost | NZD$10.82 |

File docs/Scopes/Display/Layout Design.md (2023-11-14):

#5e5ce6/projects 

# Layout Design

> [!todo] Requirements
> - [x] Minimum resolution of $20\times 15$

- I will use [[Figma]] to make these mock-ups, as I can easily create a component for the LED and the the auto-layout tool to create the desired grid for the matrix
	![[Pasted image 20231008235531.png]]

- Assuming I select the $1.6\,\text{mm}\times 1.5\,\text{mm}$ devices and a pitch of $3\,\text{mm}$, this produces a $24\times 16=384$ matrix that looks like the following:
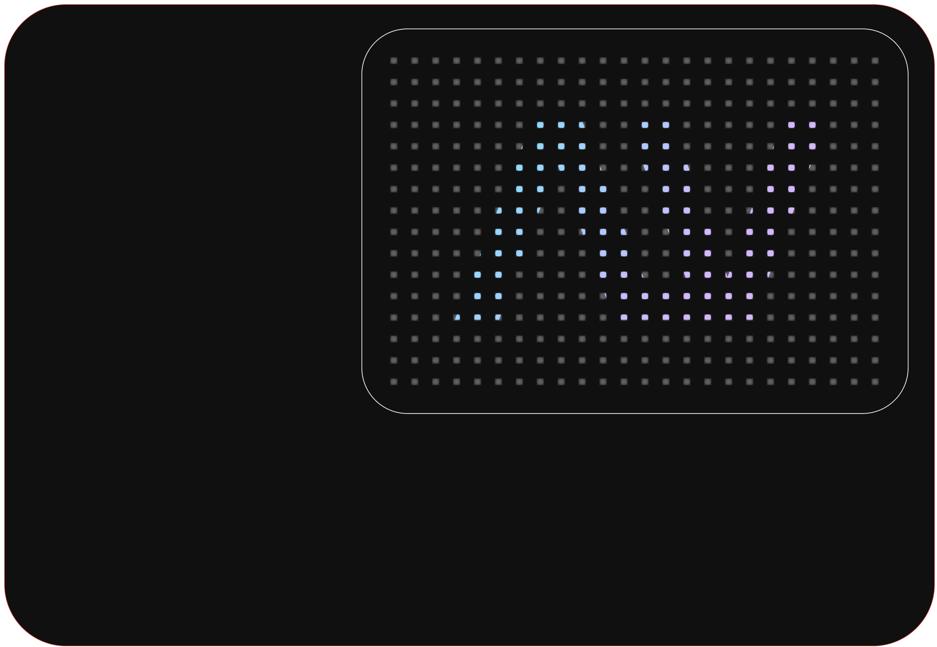
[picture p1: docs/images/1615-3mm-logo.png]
1615 3mm logo
	
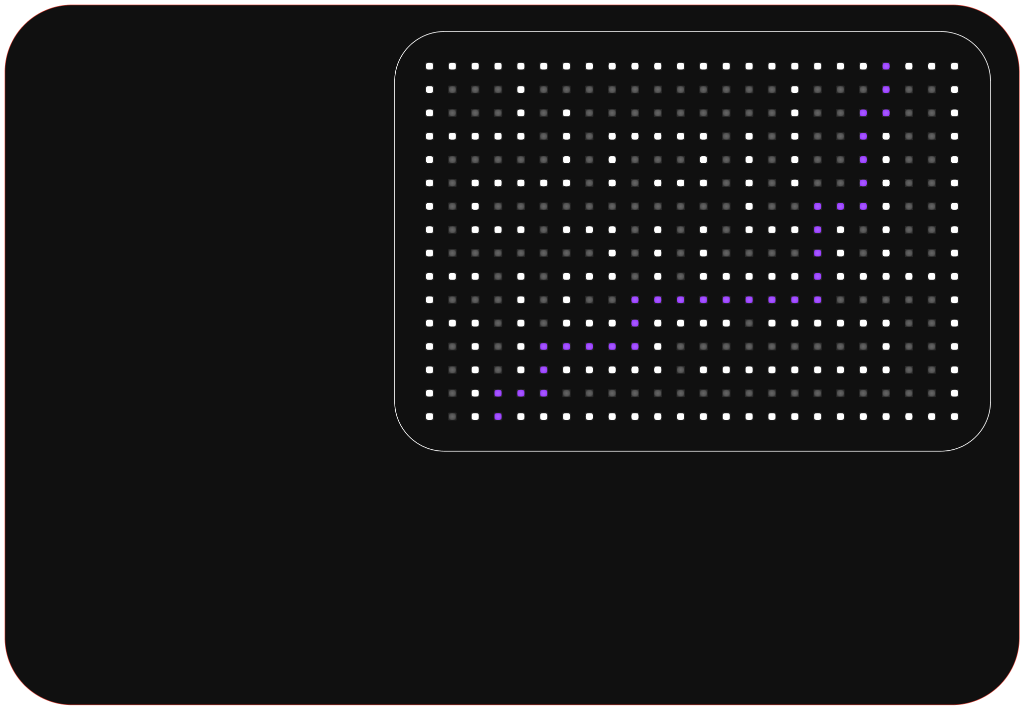
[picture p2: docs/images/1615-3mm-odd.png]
1615 3mm odd maze
	
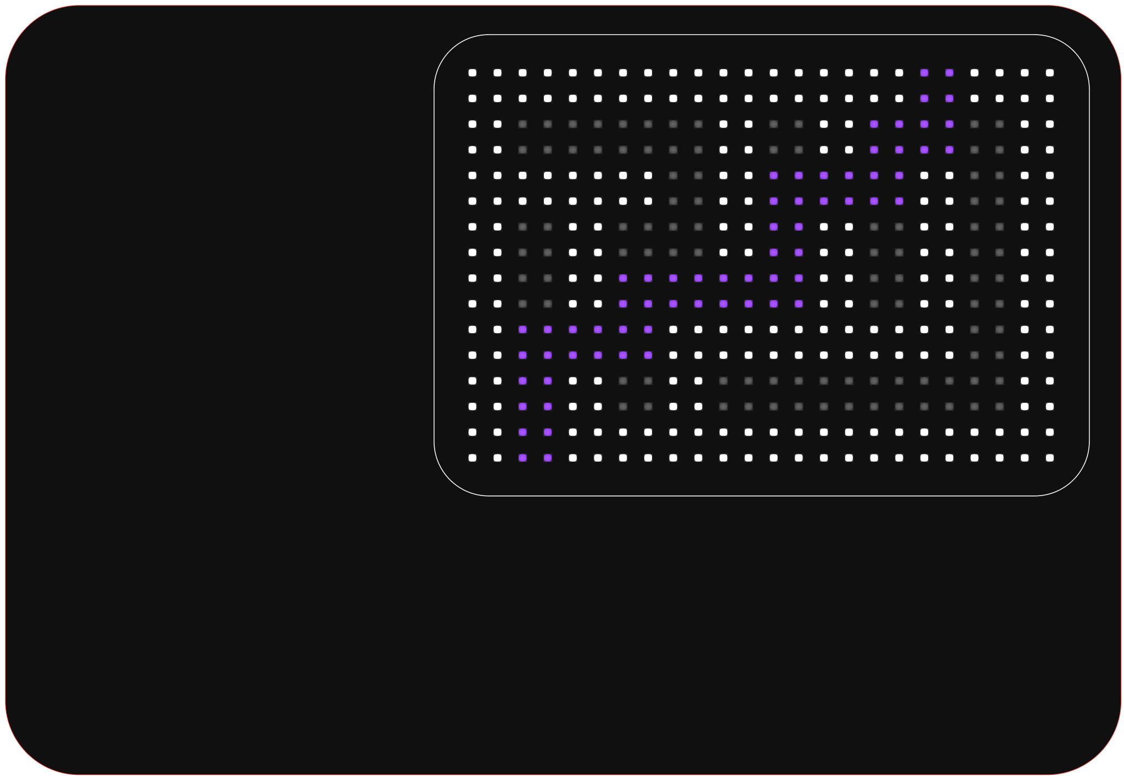
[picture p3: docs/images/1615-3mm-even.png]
1615 3mm even maze
	

- I learn that, although I can double up for an even maze, I would need many more pixels (and similarly matrix size) to have enough paths
- I do notice however that the odd maze is quite hard to read, perhaps a smaller pitch will make this better
- I will plan on moving forward with a single-pixel line width, and design for an odd-dimensioned matrix such that gaps work out as desired

- With a pitch of $2.5\,\text{mm}$, I have a $27\times 15=405$ matrix that produces
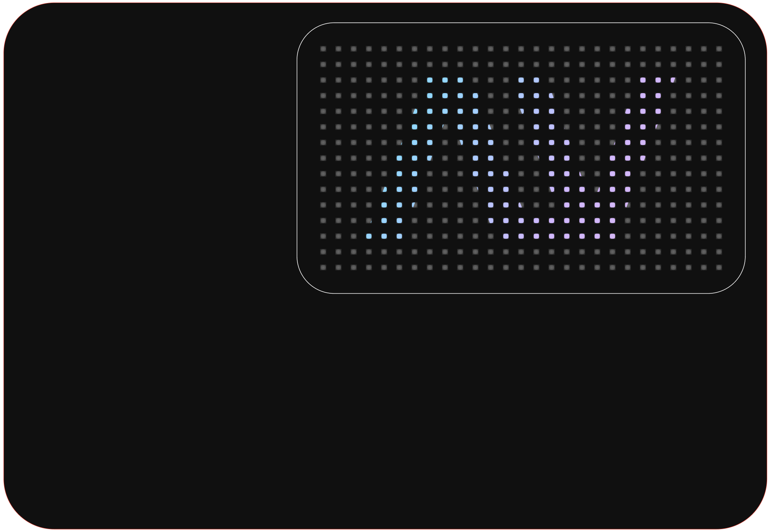
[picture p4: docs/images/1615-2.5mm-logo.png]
1615 2.5mm logo
	
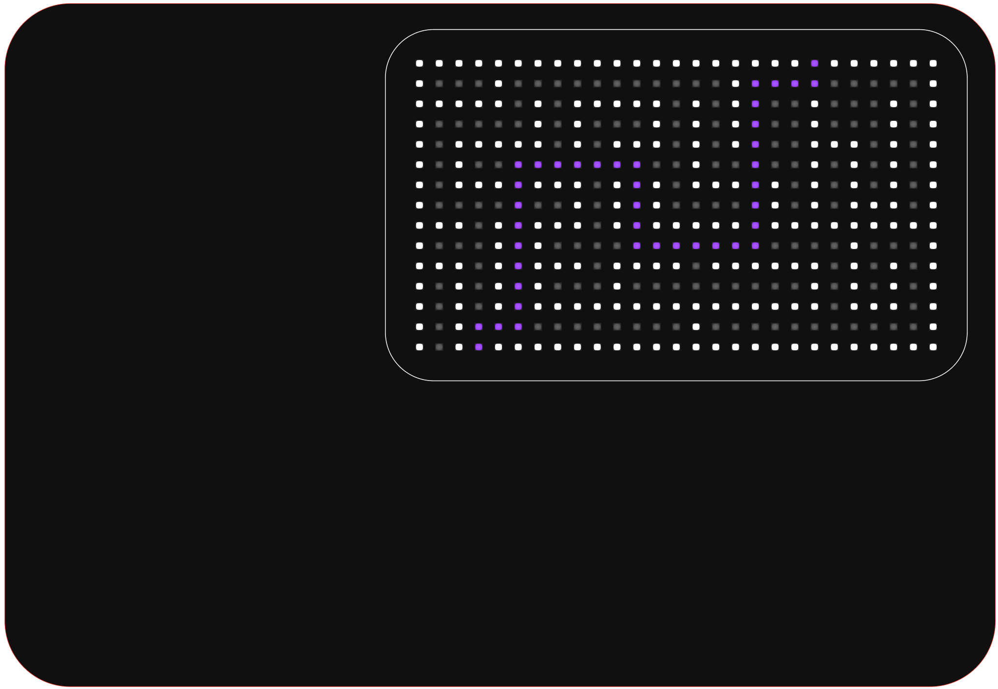
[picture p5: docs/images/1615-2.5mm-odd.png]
1615 2.5mm odd maze
	
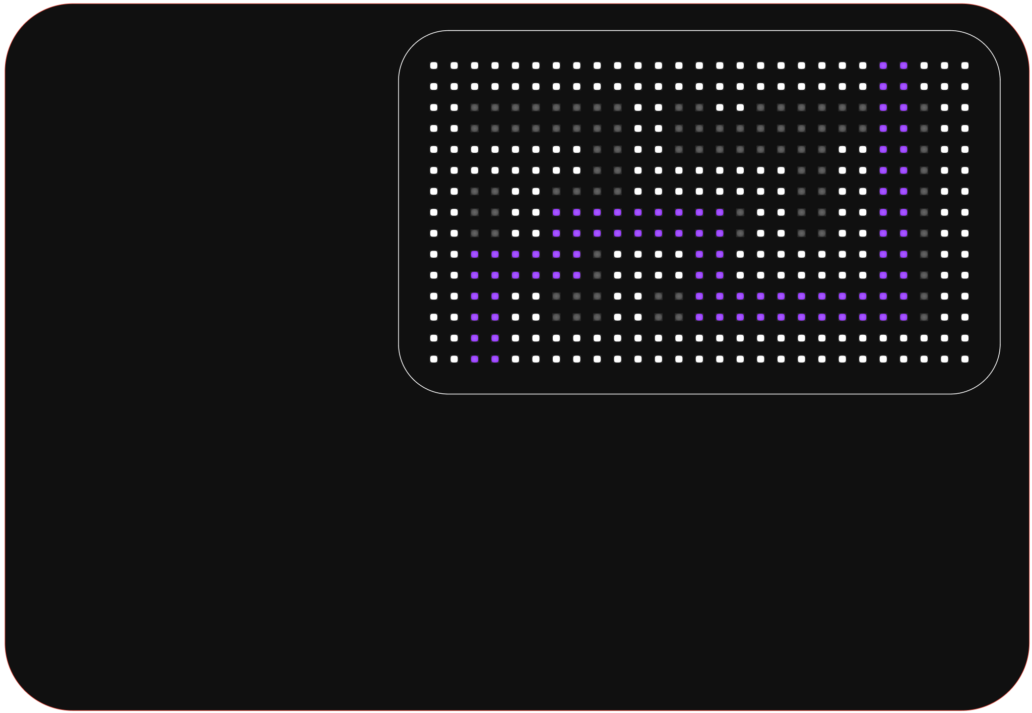
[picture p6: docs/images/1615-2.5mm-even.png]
1615 2.5mm even maze
	
 
- This definitely looks better, but I think the maze could/should still be more readable than what it is
- I chose to keep the row count to $15$, as this allows me to to use a single 48-channel LED driver to drive a whole $\frac{48}{3}=16$ LED column at once, where I can then multiplex through
- As these are not addressable LEDs (ie incorporate a controller within the LED device), they do not require local decoupling—so I do not need to account for this in designing the pitch

- Reducing the pitch to $1.6\,\text{mm}$, I have a $35\times21=735$ matrix
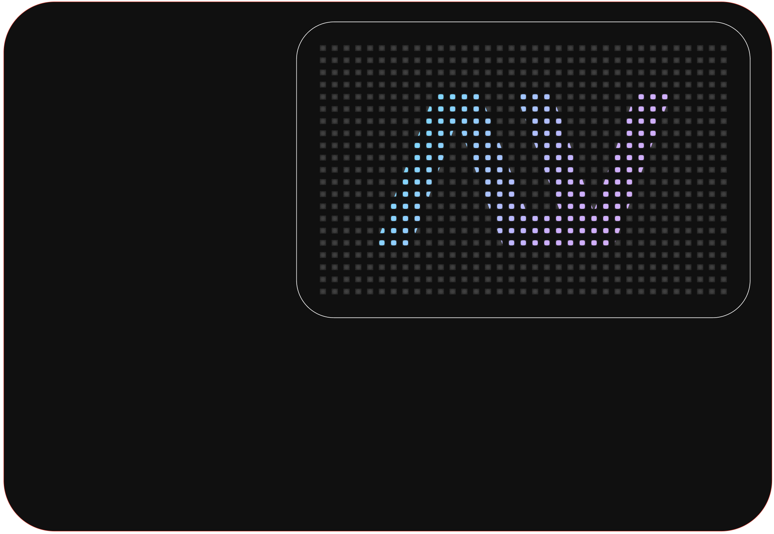
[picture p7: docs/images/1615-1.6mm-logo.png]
1615 1.6mm logo
	
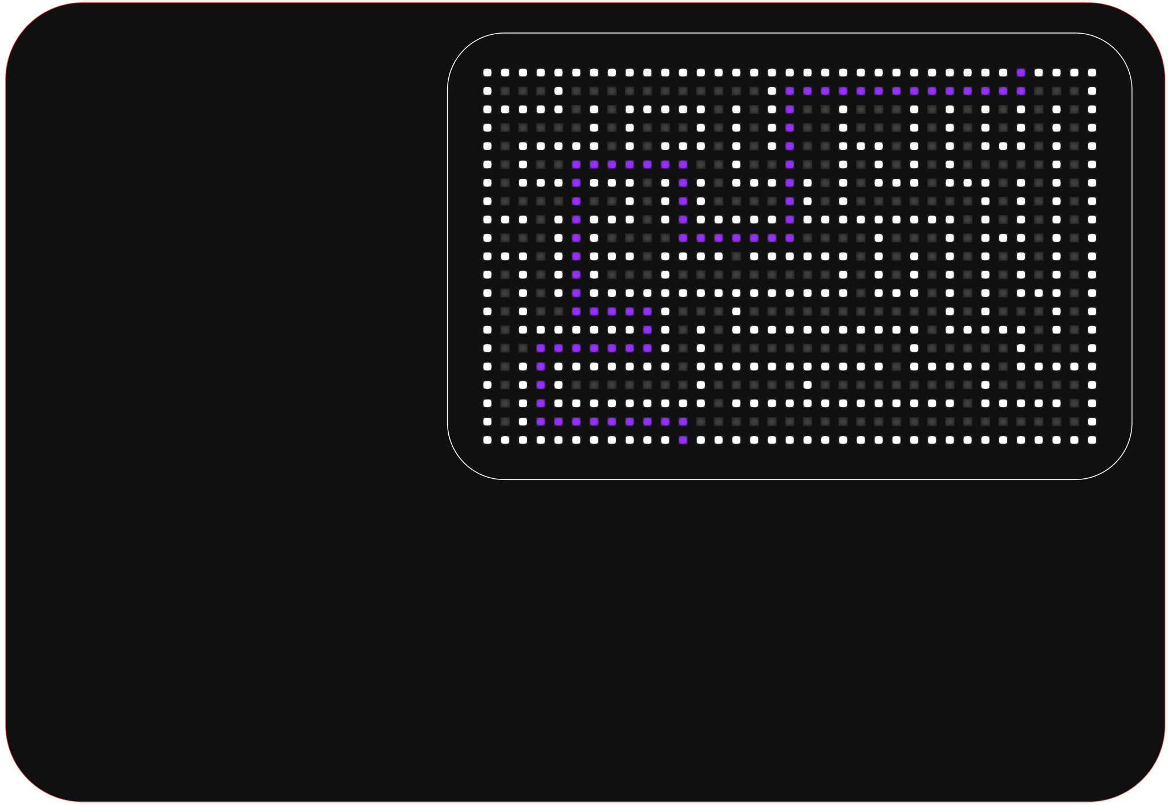
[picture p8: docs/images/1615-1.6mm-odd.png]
1615 1.6mm odd maze
	
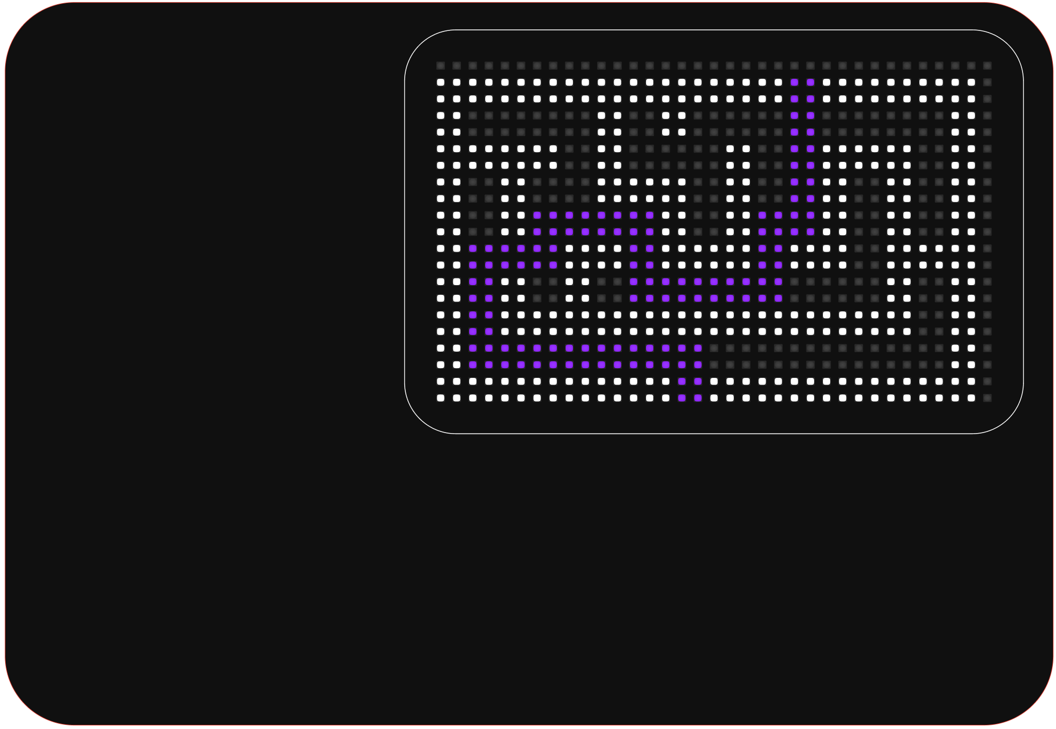
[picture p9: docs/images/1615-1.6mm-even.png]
1615 1.6mm even maze
	
 
 - I am happy with this, I think this pitch is a good balance between being realistic (assembly, pixel count—price), and being readable with a decent resolution
 - The row/column counts of 21 and 35 have also been deliberately chosen as I can use three 36-channel (ie 12 RGB LED) drivers to drive the full row, or two 36-channel drivers to drive a full column

 - In terms of the driving mechanism, my first idea would be to use the below topology, with three 36-channel drivers to drive all the columns at once, and scan through the 21 rows with a set of three 8-bit shift registers chained together
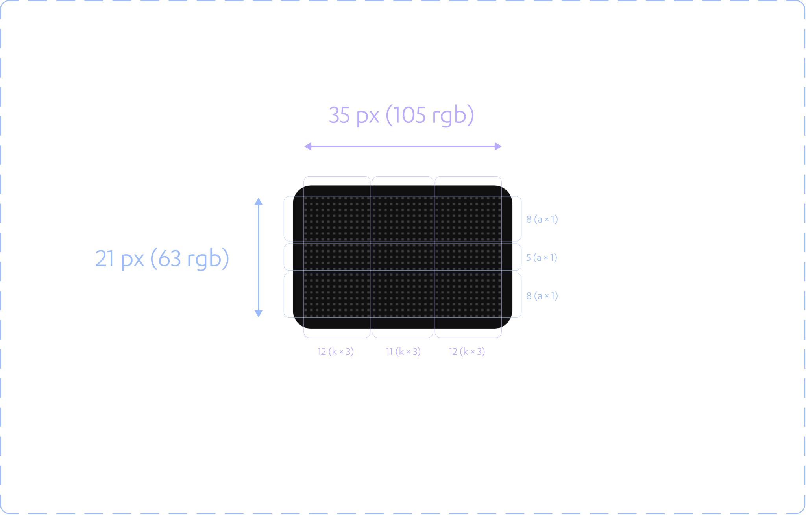
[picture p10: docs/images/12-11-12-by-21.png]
12-11-12 by 21
	 

- My next step will be to part out the [[LED Drivers]] and [[Shift Registers]] that I want to use
- A potential improvement (scan-wise) would be to add three more drivers such that I can split the rows in half, and display two whole rows at once (ie scanning through two lines at once), which would improve the refresh/scan rate of the display, at a cost of component count/cost/driver frequency

- As I am just wanting to scan through the rows one after another and do not need to load some arbitrary data into the shift register before enabling the output all at once, I will not need an output storage register
	- I can simply write the next bit into the shift register once I am ready to scan to the next row, as I only expect the shift register to contain a single `1` at any given instant
 - I also do not need a tri-state output, as the shift register output will be the only thing connected to the common anode pins (probably through a buffer transistor)

- From the LED driver perspective—I may want to use more drivers simply such that each driver is controlling less than 32 channels, so that I can represent it using a `uint32_t` rather than needing to use a whole `uint64_t` and wasting 28 bits (for a total of 87 wasted bits)
```c
#define DISPLAY_TOTAL_ROWS 35  
#define DISPLAY_TOTAL_COLUMNS 21  
#define DISPLAY_PIXEL_TOTAL_CHANNELS 3  
  
typedef uint128_t row_t;  
typedef uint32_t column_t;  
  
#define DISPLAY_DRIVER_TOTAL_ONE 12 * DISPLAY_PIXEL_TOTAL_CHANNELS  
#define DISPLAY_DRIVER_TOTAL_TWO 11 * DISPLAY_PIXEL_TOTAL_CHANNELS  
#define DISPLAY_DRIVER_TOTAL_THREE 12 * DISPLAY_PIXEL_TOTAL_CHANNELS  
  
typedef uint64_t driver_t; // !
  
row_t currentRow = 0b010/* ... */001;  
  
driver_t driverOne = (currentRow <<= DISPLAY_DRIVER_TOTAL_ONE);  
driver_t driverTwo = (currentRow <<= DISPLAY_DRIVER_TOTAL_TWO);  
driver_t driverThree = (currentRow <<= DISPLAY_DRIVER_TOTAL_THREE);
```
- Another option I have is to reduce the column count from 35 to 31, producing a more square matrix
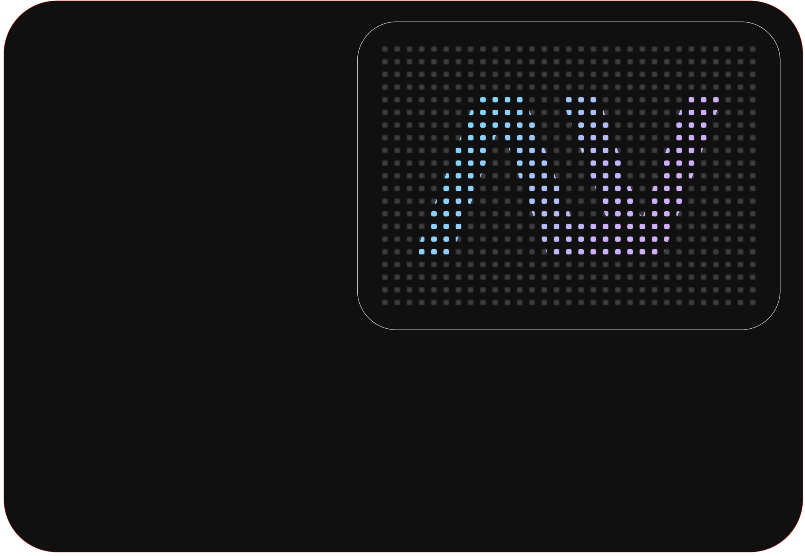
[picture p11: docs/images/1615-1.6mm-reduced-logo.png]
1615 1.6mm reduced logo
	
	- I'm not sure how I feel about this, I think I will pursue the alternative of simply using more drivers for the time being
	- This may work out to be the better decision regardless, as I would expect 24-channel drivers to be easier to source than 48-channel drivers
	- Furthermore, a quick cursory search on DigiKey suggests that 24-channel drivers can be found that sink significantly more ($60\,\text{mA}$ vs $30\,\text{mA}$) current than 48-channel drivers
	- Also, although I can find 36-channel drivers, I can only find them in quad flat packages (and with less current capability), whilst I'd prefer a SOP package for routing/aesthetics

Having selected my [[Shift Registers]] and [[LED Drivers]] to produce the final layout shown below, I will now work through the below design tasks to determine my matrix [[Design Parameters]].
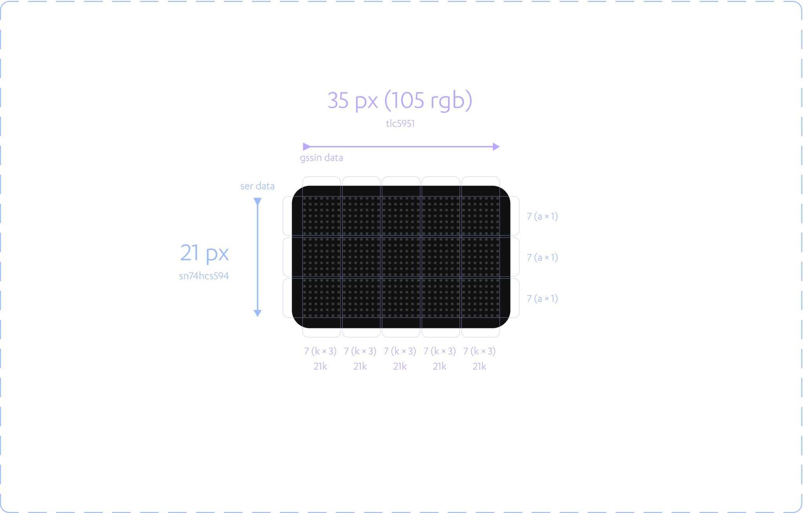
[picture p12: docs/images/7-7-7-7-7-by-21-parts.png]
7-7-7-7-7 by 21 with parts
	 
  
> [!todo]
> - [x] Work out the minimum data frequency if I want a refresh rate of $\geq 60\,\text{Hz}$
> - [x] Work out the worst-case current if all LEDs in a row are at full brightness white—this cannot be sourced by the shift register, so I must design a current amplifier stage
> - [x] Refer to the [`TLC5955`](https://www.digikey.co.nz/en/products/detail/texas-instruments/TLC5955DCAR/5181329) and [`TLC5947`](https://www.digikey.co.nz/en/products/detail/texas-instruments/TLC5947DAPR/2047743) datasheets for guidance on design procedure/power supply recommendations etc.

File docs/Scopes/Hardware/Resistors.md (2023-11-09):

#5e5ce6/projects 

# Resistors

To select the resistors that I will use for this project, I will again perform a parametric search on DigiKey as in [[P-Channel MOSFETs]].

I will first just select a specific family/product line of resistors, within which I will order the values that I need.

Firstly, applying a search filter to only parts that are:
1. surface mount,
2. in stock,
3. available as Cut Tape,
4. active product status, and
5. have a datasheet,
I narrow down the product selection from over 1 million to 88 thousand.

I further filter the results by looking for resistors that are $\pm1\%$ tolerance or better, and sort by a pricing quantity of $50$ to avoid results where I would not satisfy the minimum order quantity.

In order to narrow down to a specific series, I will apply a further filter for an arbitrary resistance value—say $100\,\Omega$—such that I would get a single result from each product line. This narrows the selection down to just [105 results](https://www.digikey.co.nz/short/rnzd1jrd).

![[Pasted image 20231109174434.png]]

Sorting by price, I see that the top results are all effectively equivalent in their ratings, and all feature a thick film composition—the characteristics of which are definitely suitable for my application. I see that the series with the largest available stock quantity is the `RC_L` General Purpose Chip Resistor series from `YAGEO`, which are available in a wide variety of package sizes.

I intend to primarily use `0402` (imperial) size devices in this project—at least in the display section—which are available as both $1/16\,\text{W}$ and $1/8\,\text{W}$ devices and up to the `E96` series. I may decide to use larger `0603` or `0805` components in other sections of the board, which are available as $1/10\,\text{W}$ & $1/5\,\text{W}$ and $1/8\,\text{W}$ and $1/4\,\text{W}$ devices respectively.

> [!success] Preferred Series
> I will use devices from the YAGEO [`RC_L`](https://www.yageo.com/en/Product/Index/rchip/thick_film_general_purpose) thick film general purpose resistor series.

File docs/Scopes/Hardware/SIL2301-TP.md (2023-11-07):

#5e5ce6/projects 

# `SIL2301-TP`

> [!success] Preferred Device
> The best device appears to be the [`SIL2301-TP`](https://www.digikey.co.nz/en/products/detail/micro-commercial-co/SIL2301-TP/9655969), with its electrical characteristics & physical package/pinout.
> 
> Refer to [[P-Channel MOSFETs]] for full details.

| Part Number | `SIL2301-TP` |
| --- | --- |
| Image |  |
| Supplier Link | [DigiKey](https://www.digikey.co.nz/en/products/detail/micro-commercial-co/SIL2301-TP/9655969) |
| Datasheet | [Datasheet](https://www.mccsemi.com/pdf/Products/SIL2301(SOT23-6L).pdf) |
| Pins | 6 |
| Package | `SOT23-6L` |
| FETs in Package | 2 |
| Pin Pitch | $0.95\,\text{mm}$ |
| Drain to Source Voltage | $20\,\text{V}$ |
| Gate to Source Voltage | $8\,\text{V}$ |
| Continuous Drain Current | $2.3\,\text{A}$ |
| Drain to Source On Resistance | $58\,\text{m}\Omega$ |
| Power Dissipation | $1.25\,\text{W}$ |
| Gate Charge | $5.5\,\text{nC}$ |
| Input Capacitance | $405\,\text{pF}$ |
| Cost (for 8) | USD$3.36 |

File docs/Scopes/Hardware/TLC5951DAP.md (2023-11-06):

#5e5ce6/projects 

# `TLC5951DAP`

> [!success] Preferred Device
> The best device seems to be the [`TLC5951DAP`](https://www.digikey.co.nz/en/products/detail/texas-instruments/TLC5951DAP/2187574) due to its maximum output current and brightness/dimming controls/data frequency.
> 
> Refer to [[LED Drivers]] for full details.

| Part Number | `TLC5951DAP` |
| --- | --- |
| Image |  |
| Supplier Link | [DigiKey](https://www.digikey.co.nz/en/products/detail/texas-instruments/TLC5951DAP/2187574) |
| Datasheet | [Datasheet](https://www.ti.com/general/docs/suppproductinfo.tsp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) | 
| Input Pins | 10 |
| Package | `38-HTSSOP` |
| Pin Pitch | $0.65\,\text{mm}$ |
| Channels | 24 |
| Protocol | Shift register |
| Dimming | Analogue global, PWM greyscale |
| Greyscale Resolution | 12 bit |
| Global Brightness Control | 8 bit, external resistors |
| Voltage | $3\sim5.5\,\text{V}$ |
| Max Current per Channel | $40\,\text{mA}$ |
| Max GND Current | |
| Max Frequency | $30\,\text{MHz}$ |
| Cost (for 5) | USD$21.90 |

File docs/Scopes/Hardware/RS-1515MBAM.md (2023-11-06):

#5e5ce6/projects 

# `RS-1515MBAM`

> [!success] Preferred Device
> Chosen for price, lens, and forward current.
> 
> Refer to [[Discrete Non-Addressable RGB LEDs]] for full details.

| Part Number | `RS-1515MBAM` |
| --- | --- |
| Image |  |
| Supplier Link | [LCSC](https://www.lcsc.com/product-detail/Light-Emitting-Diodes-LED_Foshan-NationStar-Optoelectronics-RS-1515MBAM_C727906.html) |
| Datasheet | [Datasheet](https://datasheet.lcsc.com/lcsc/2009051636_Foshan-NationStar-Optoelectronics-RS-1515MBAM_C727906.pdf) |
| Colour | RGB |
| Lens | Diffused square |
| Package/Dimensions | $1.6\,\text{mm} \times 1.5\,\text{mm} \times 1\,\text{mm}$ |
| Absolute Maximum Voltage | $3.4\,\text{V}$ |
| Average Forward Current  | $50\,\text{mA}$ |
| Configuration | Common anode |
| Data Lines | $\geq 3$ GPIO pins |
| Cost (for 256) | USD$4.47 |

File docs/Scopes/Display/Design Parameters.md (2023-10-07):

#5e5ce6/projects 

# Design Parameters

- [[Minimum Data Frequency]]
- [[Maximum Output Constant-Current]]
- [[Maximum LED Forward Voltage]]
- [[White Balance]]
- [[Uniformity]]
- [[Pixel Brightness]]
- [[Auto Display Repeat]]
- [[Display Timing Reset]]

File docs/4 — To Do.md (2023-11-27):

#5e5ce6/projects 

# To Do

> [!note]
> This is a living document to track incomplete tasks—think of it as a stack frame.

## Hardware

- [[Oscillators]]
	- Greyscale reference clock

- Select [[Ferrite Beads]]
 
## PCB

- [[PCB Fabricators]]
- Mezzanine connectors? [Mezzanine Products, Search by Picture | Samtec](https://www.samtec.com/picturesearch/high-speed-board-to-board/mezzanine)

- Figure out component solder mask expansion rules

- DNP extra decouplings

- Net colouring
- Draftsman

## Power

[bypassing.pdf (designers-guide.org)](https://designers-guide.org/design/bypassing.pdf)
[szza009.pdf (ti.com)](https://www.ti.com/lit/an/szza009/szza009.pdf)

SPICE model to model my supply/power net and switching activity

- [[Buck Converter]]
- [[Low Dropout Regulator]]

- [[Load Switch]]
- [[Current Sensing]]
- [[Input Protection]]
- [[Auto-Shutdown]]

## Interface

- [[Brightness Control]]
- [[Operating Modes]]
- [[User Pushbuttons]]
- [[Debug LEDs]]

## Display

- [[VLED Bypassing]]
- [[Current Amplifier]] re-design with input-voltage tolerance

## Microcontroller and Programming

- Microcontroller schematic design docs
	- Decoupling
	- Crystals
	- Cube pinout

- [[Scopes/Micro/USB to Serial]]
- [[Programming]]
- [[Connectivity]]

- set up [[UCPD]]
- use cubemx to configure pinout

- Select an [external module](https://pcbartists.com/design/embedded/stm32-wifi-options/) for connectivity

## Firmware

- Dot correction calibration in EEPROM

## Algorithms

- [pran01/AlgoVision](https://github.com/pran01/AlgoVision)

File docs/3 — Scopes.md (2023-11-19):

#5e5ce6/projects 

# Scopes

> [!IMPORTANT]  
> See also [[1 —  Goals]] and [[2 — Specifications]].

---

- [[Assets]]
- [[Hardware]]
- [[PCB]]
- [[Power]]
- [[Interface]]
- [[Display]]
- [[Microcontroller and Programming]]
- [[Firmware]]
- [[Algorithms]]

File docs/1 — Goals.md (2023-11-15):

#5e5ce6/projects 

# Goals

> [!NOTE]  
> This document lists the goals and outcomes that this project should aim to accomplish.

---

1. To complete a project that envelops hardware, firmware, and (possibly) software design

2. To revise data structures/[[algorithms]] and visualise common [[sorting]] and [[pathfinding]]/[[search]] algorithms in an easily-understood manner

3. To revise [[Scopes/Micro/Microcontroller|microcontroller]] concepts and available peripherals—eg timers/counters, GPIOs, serial communication, shift registers/multiplexing for matrix displays, etc.

4. To (finally) follow one of my own [[PCB]] designs through to fabrication/assembly/seeing it work

5. To complete a project that is self-contained and accessible—ideally should not require any extraneous equipment—eg no special load/supply/test environment/etc.

6. To learn about the [[USB]] protocol

7. To learn more about another microcontroller—possibly the [[ESP8266]]/[[ESP32]], or maybe a [[PSoC 6]]

8. To have something else that I can show off to demonstrate my knowledge and design ability

9. To have something that other students could potentially use to help learn about different algorithms

10. To apply my existing understanding of electronics and analogue design and build my confidence, whilst diving deeper and learning new concepts

11. To test my understanding of how [[Display|displays]]/matrices are driven

12. To have something to help show off Electrical/Computer Engineering!!!

13. To understand and design how [[Boost Converter|buck/boost converters]] work—if applicable

14. To write as much of my own driver firmware as possible, rather than relying on external/3rd party libraries

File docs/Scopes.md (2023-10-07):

#5e5ce6/projects 

# Scopes

> [!IMPORTANT]  
> See also [[Goals]] and [[Specifications]]

---

- [[Assets]]
- [[PCB]]
- [[Power]]
- [[Interface]] and User Input 
- [[Display]]
- [[Microcontroller and Programming]]
- [[Algorithms]]

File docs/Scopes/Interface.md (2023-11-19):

#5e5ce6/projects 

# Interface

- [[Operating Modes]]
- [[User Pushbuttons]]
- [[Debug LEDs]]
- [[Brightness Control]]

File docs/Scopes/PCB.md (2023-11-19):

#5e5ce6/projects 

# PCB

https://github.com/JamesNZL/algovision/issues/10
- [[PCB Fabricators]]

- [[Schematic Guidelines]]
- [[Artwork Guidelines]]

- Should I make it a double stacked board? Mezzanine connectors?
	[Search by Picture, You'll Know It When You See It | Samtec](https://www.samtec.com/picturesearch/)

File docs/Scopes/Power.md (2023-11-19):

#5e5ce6/projects 

# Power

- [[Batteries]]
- [[Battery Voltage Sensing]]
- [[Load Switch]]
- [[Auto-Shutdown]]

- [[Boost Converter]]
- [[Buck Converter]]
- [[Low Dropout Regulator]]

- [[USB Power Delivery]]
- [[Current Sensing]]

- [[Input Protection]]

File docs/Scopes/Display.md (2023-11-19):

#5e5ce6/projects 

# Display

## Features

- Ideally want RGB support—want to have RGB rainbows etc
	- This only really works with an LED matrix though, an RGB rainbow on an LCD/OLED display is boring
- Should have sufficient resolution to display the logo
	- Minimum size of $20\times15$ LEDs to effectively show pathfinding
 
## Component Selection

I will need to consider, among other things:
	1. Operating voltages;
	2. Typical current draw;
	3. Communication/driving protocol (data lines required, [[Microcontroller|microcontroller]] peripherals needed); and
	4. Cost.
 
## Design Process

First, I will begin by doing a [[Parts Selection]] by comparing different options, and selecting the device(s) that I think will be the most suitable.

Having evaluated the different options I can elect to go with, I have decided to proceed with a [[Discrete LED Matrix]], and specifically the preferred devices identified in [[Discrete Non-Addressable RGB LEDs]].

Having done my parts selection, I will move on to a [[Layout Design]] in [[Figma]] using my selected devices to design the matrix layout and topology itself.

After choosing my [[Shift Registers]] and [[LED Drivers]] to drive my matrix, I will work through determining the [[Design Parameters]] that I will need to know in order to use the selected LED driver.

I also needed to design a simple [[Current Amplifier]] stage for the common-anode input of each LED, as the shift register can only source $\approx 7\,\text{mA}$ per output.

Lastly, I needed to determine the necessary [[VLED Bypassing]] [[Capacitors]] to produce a 'well-regulated LED supply voltage ($V_\text{LED}$).

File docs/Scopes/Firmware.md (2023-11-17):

#5e5ce6/projects 

# Firmware

- [[Watchdog Timer]]

## Display

- [[Frame Buffers]]

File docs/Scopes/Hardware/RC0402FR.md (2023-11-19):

#5e5ce6/projects 

# `RC0402FR`

> [!success] Preferred Series
> I will use devices from the YAGEO [`RC_L`](https://www.yageo.com/en/Product/Index/rchip/thick_film_general_purpose) thick film general purpose resistor series.
> 
> Refer to [[Resistors]] for full details.

| Part Number | `RC0402FR` |
| --- | --- |
| Image |  |
| Supplier Link | [DigiKey](https://www.digikey.co.nz/short/3q37wvp0) |
| Datasheet | [Datasheet](https://www.yageo.com/upload/media/product/productsearch/datasheet/rchip/PYu-RC_Group_51_RoHS_L_12.pdf) |
| Terminals | 2 |
| Package | `0402` |
| Tolerance | $\pm1.0\%$ |

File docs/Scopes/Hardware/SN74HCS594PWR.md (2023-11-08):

#5e5ce6/projects 

# `SN74HCS594PWR`

> [!success] Preferred Device
> The best device seems to be the [`SN74HCS594PWR`](https://www.digikey.com.au/en/products/detail/texas-instruments/SN74HCS594PWR/13532304) with its shift & storage clocks tied together—so I will move forward with this
> 
> Refer to [[Shift Registers]] for full details.

| Part Number | `SN74HCS594PWR` |
| --- | --- |
| Image |  |
| Supplier Link | [DigiKey](https://www.digikey.co.nz/en/products/detail/texas-instruments/SN74HCS594PWR/13532304) |
| Datasheet | [Datasheet](https://www.ti.com/lit/ds/symlink/sn74hcs594.pdf) | 
| Pins | 16 |
| Package | `16-TSSOP` |
| Pin Pitch | $0.65\,\text{mm}$ |
| Bits | 8 |
| Input Enable | No |
| Schmitt Inputs | Yes |
| Output Enable | No |
| Inverted Outputs | No |
| Output Storage Register | Yes |
| Output | Push-pull |
| Function | S to P |
| Voltage | $2 \sim 6\,\text{V}$ |
| Max Current | $35\,\text{mA}$ |
| Max Frequency | $100\,\text{MHz}$ |
| Clock Edge | Rising |
| Cost (for 3) | USD$1.29 |

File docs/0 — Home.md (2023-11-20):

#5e5ce6/projects 

# algovision

<div align="center">
   
</div>

A self-driven project to design an algorithm visualisation tool with a union of hardware and firmware.

## Pages

- [[1 —  Goals]]  
- [[2 — Specifications]]  
- [[3 — Scopes]]  

## Software Used

| Package | Used for |
| --- | --- |
| [[Obsidian]] | The scratch pad for documentation and design. |
| [[Visual Studio Code]] | The text editing and firmware development. |
| [[STM32CubeMX]] | The peripheral configuration and initialisation code generation. |
| [[LTspice]] | The hardware simulation and verification. |
| [[Altium\|Altium Designer]] | The schematic capture and PCB artwork. |
| [[MATLAB]] | The electrical design analysis and verification. |
| [[SOLIDWORKS]] | The 3D models of components. |
| [[Concepts]] | The rough sketches and ideation. |
| [[Figma]] | The iterative matrix mockups and topology design. |
| [[Illustrator\|Adobe Illustrator]] | The algovision logo. |

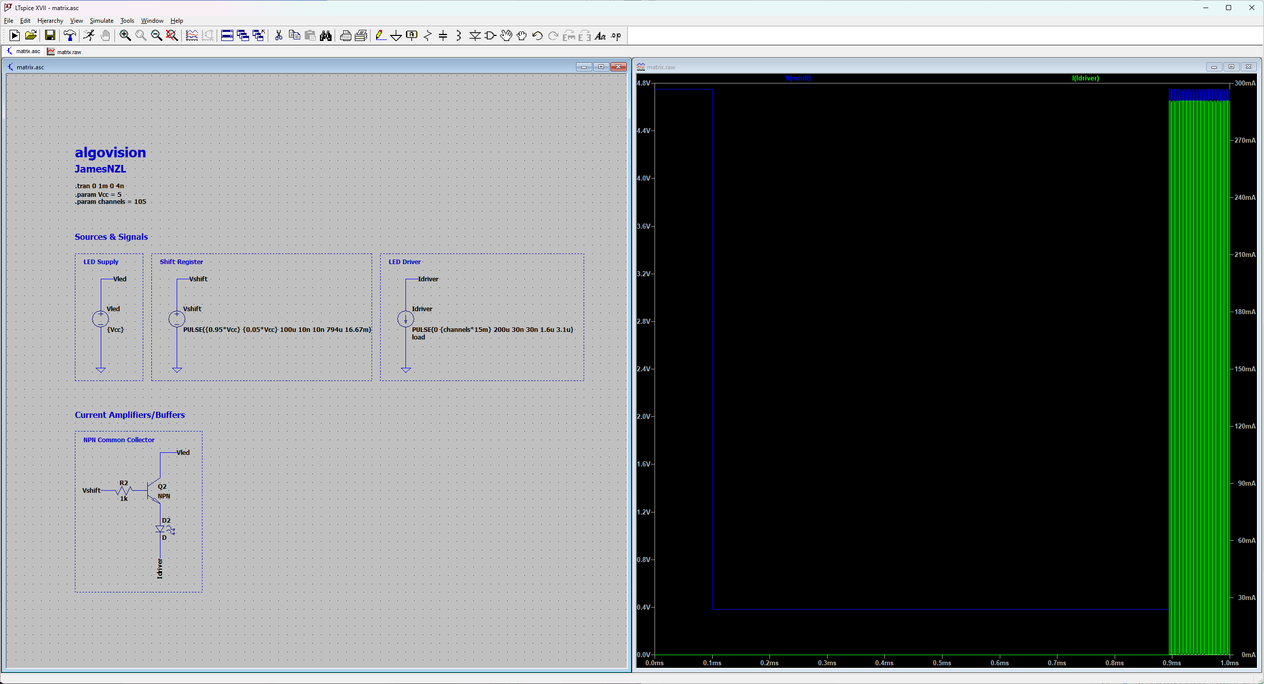
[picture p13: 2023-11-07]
docs/images/Pasted image 20231107172432.png

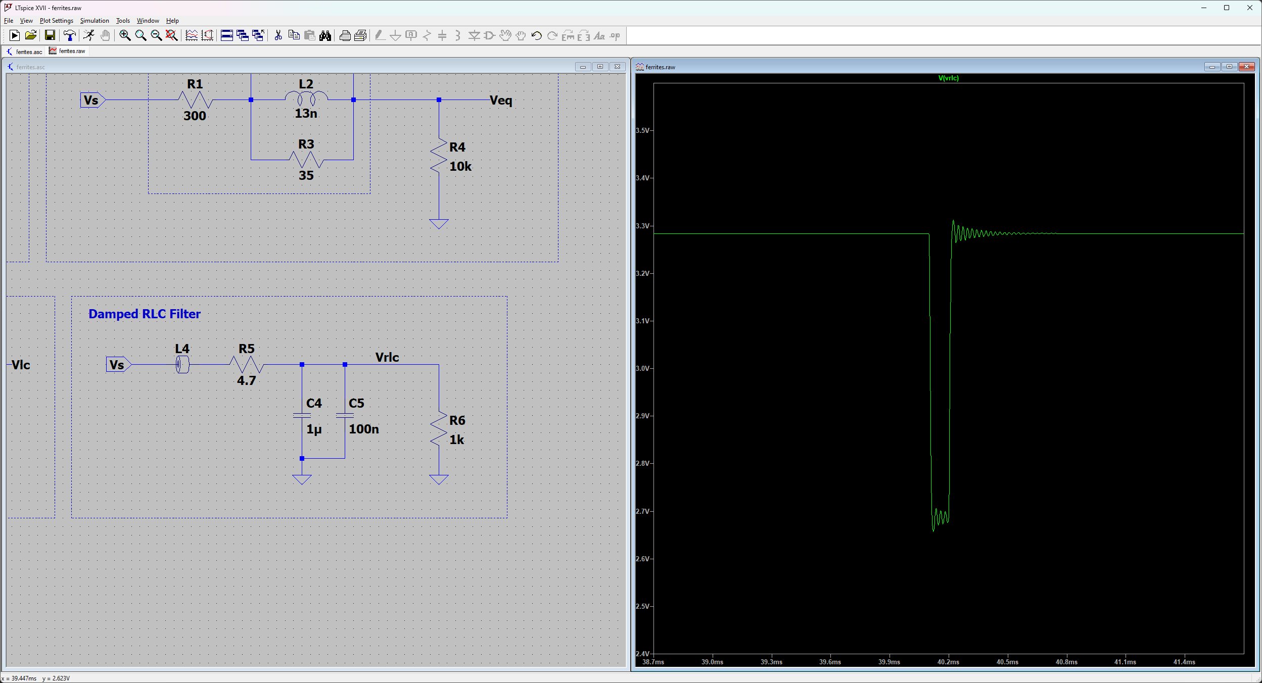
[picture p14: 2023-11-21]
docs/images/Pasted image 20231121165318.png

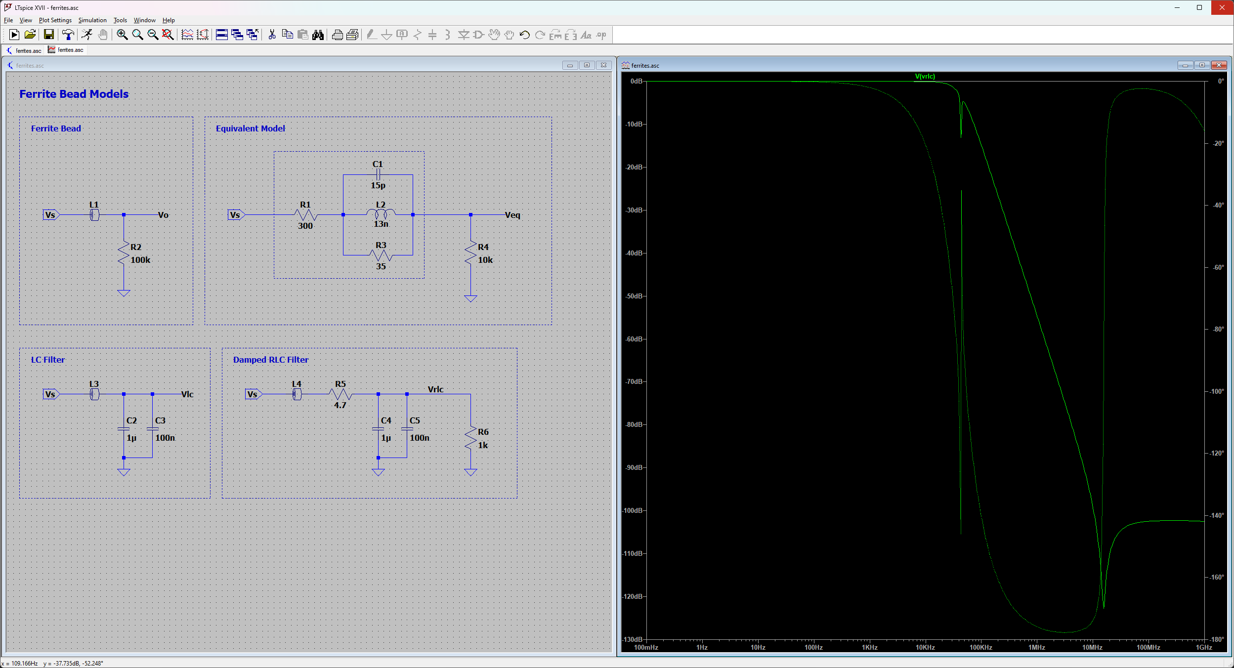
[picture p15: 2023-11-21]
docs/images/Pasted image 20231121165057.png

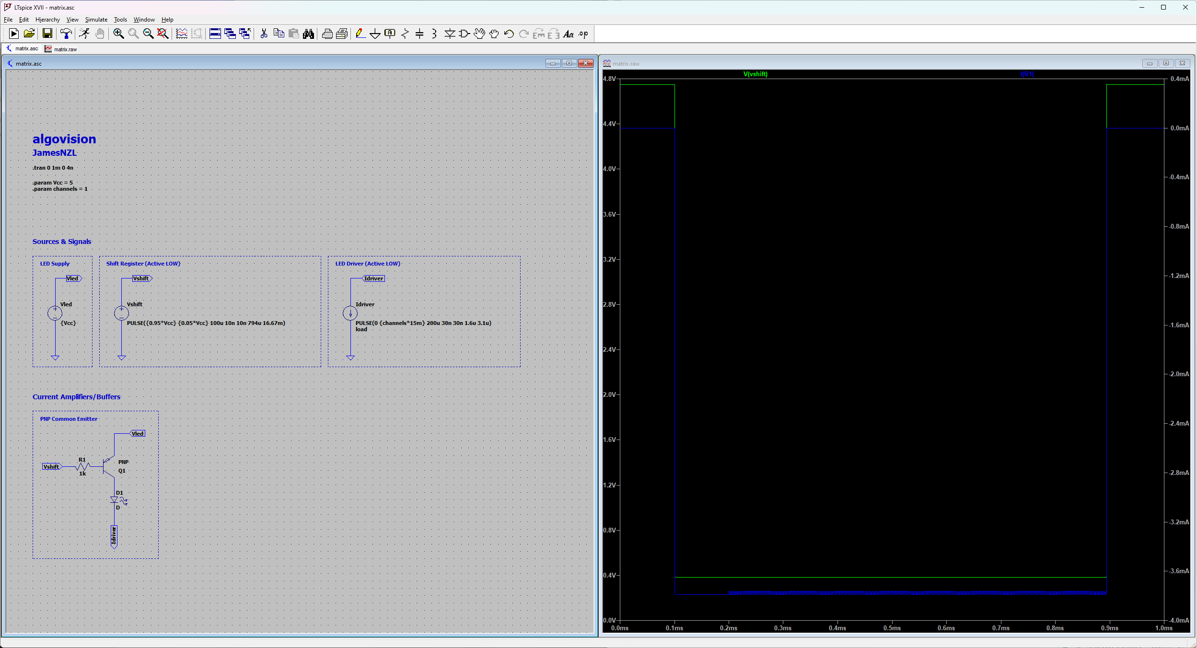
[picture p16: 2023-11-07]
docs/images/Pasted image 20231107190551.png

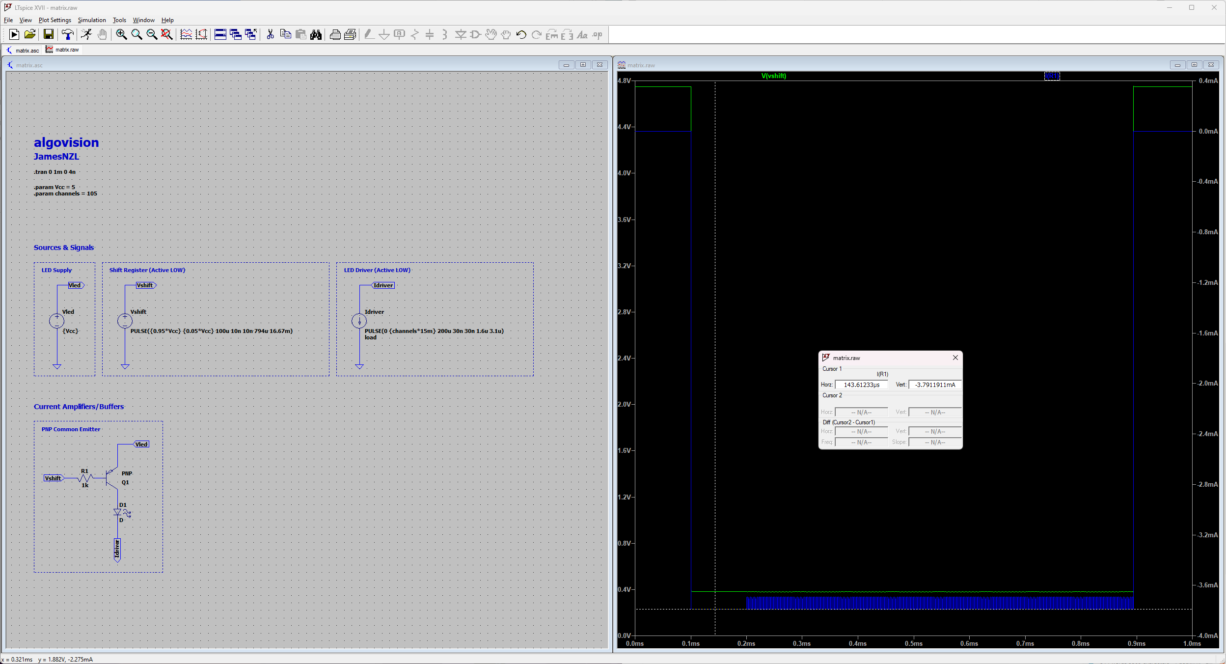
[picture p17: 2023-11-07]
docs/images/Pasted image 20231107190818.png

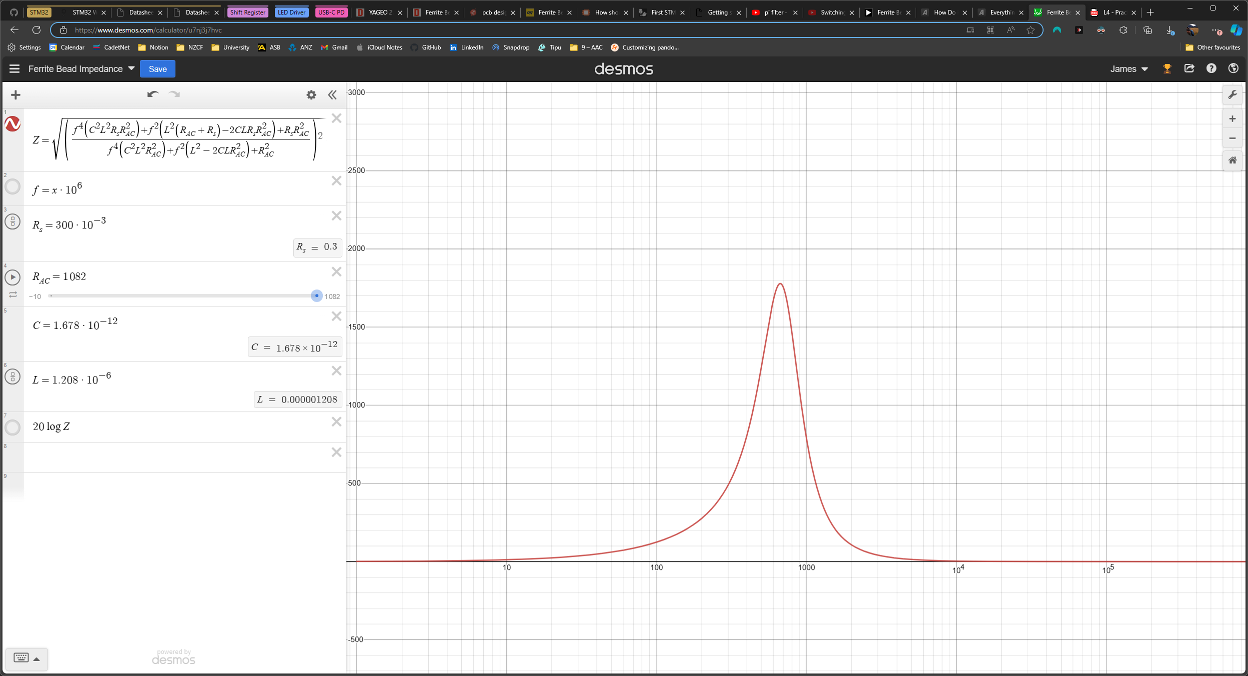
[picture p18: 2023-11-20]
docs/images/Pasted image 20231121012434.png

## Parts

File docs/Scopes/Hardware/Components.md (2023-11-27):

#5e5ce6/projects 

# Components

> [!summary] DigiKey List
> View the full DigiKey list [here](https://www.digikey.co.nz/en/mylists/list/MLSM9W9TUP).

## Passives Selection

- [[Resistors]]
- [[Capacitors]]
- [[Oscillators]]
- [[Ferrite Beads]]

## Display

- [[Parts Selection]]
	- [[Shift Registers]]
	- [[LED Drivers]]
	- [[Discrete Non-Addressable RGB LEDs]]
- [[P-Channel MOSFETs]]

| Purpose | Part Number | Quantity |
| --- | --- | --- |
| LED | [[RS-1515MBAM]] | 735 |
| Shift Register | [[SN74HCS594PWR]] | 3 |
| Shift Register Reset Pull-Up | [[RC0402FR]] (10k) | 1 |
| Shift Register Decoupling | [[CC0402KRX7R7]] (0u1) | 3 |
| LED Driver | [[TLC5951DAP]] | 5 |
| LED Driver $R_\text{IREF}$ | [[RC0402FR]] (3k24) | 5 |
| LED Driver Decoupling | [[CC0402KRX7R7]] (0u1) | 5 |
| Current Amplifier | [[SIL2301-TP]] | 12 |
| Amplifier Gate In-Rush Limiting | [[RC0402FR]] (1k) | 21 |
| Amplifier Gate Pull-Up | [[RC0402FR]] (10k) | 21 |

## Microcontroller

- [[Microcontroller]]
	- [[STM32]]

| Purpose | Part Number | Quantity | |
| --- | --- | --- | --- |
| Application Microcontroller | [[STM32U575CIT6Q]] | 1 | |
| Microcontroller $V_\text{DD}$ Bulk Decoupling  | [[CC1206KKX7R8]] (10u) | 1 | |
| Microcontroller $V_\text{DDA}$ Bulk Decoupling | [[CC0603KRX7R7]] (1u)  | 1 | |

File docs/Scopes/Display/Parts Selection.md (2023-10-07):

#5e5ce6/projects 

# Parts Selection

- [[Discrete LED Matrix]]
- [[LED Matrix Module]]
- [[Dot Matrix Module]]
- [[LCD Module]]
- [[OLED Module]]
- [[TFT Display]]

- [[Shift Registers]]
- [[LED Drivers]]

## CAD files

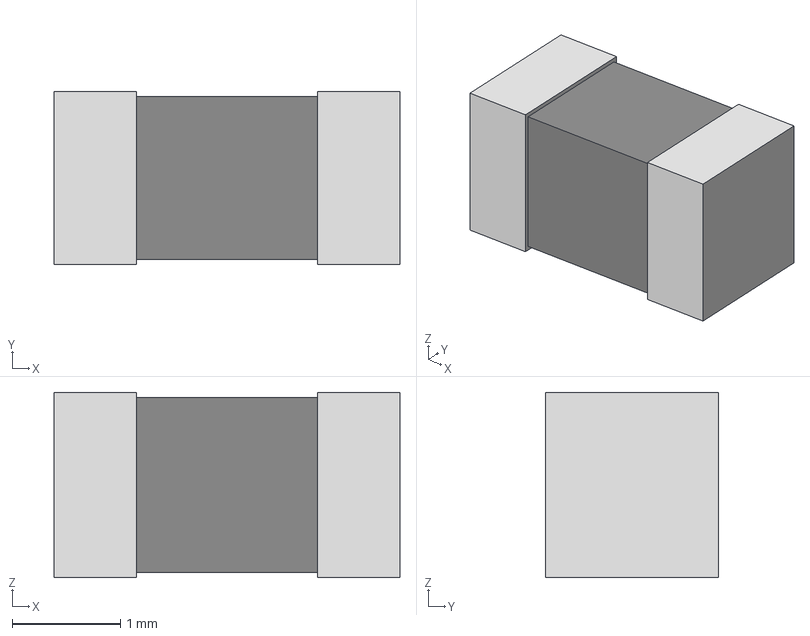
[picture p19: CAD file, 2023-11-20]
hardware/models/CC1206KK.step
3.20 x 1.60 x 1.71 mm

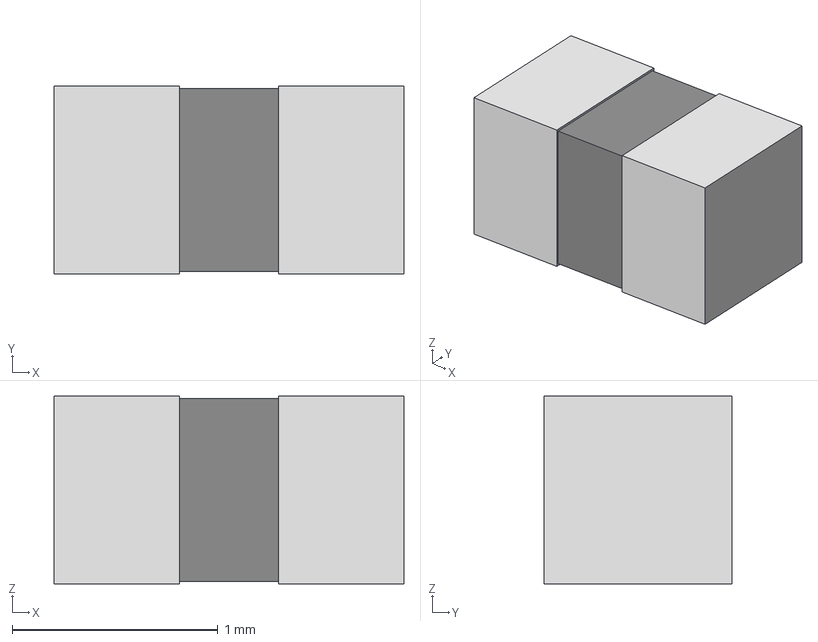
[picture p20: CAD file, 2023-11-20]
hardware/models/CC0603KR.step
1.70 x 0.914 x 0.914 mm

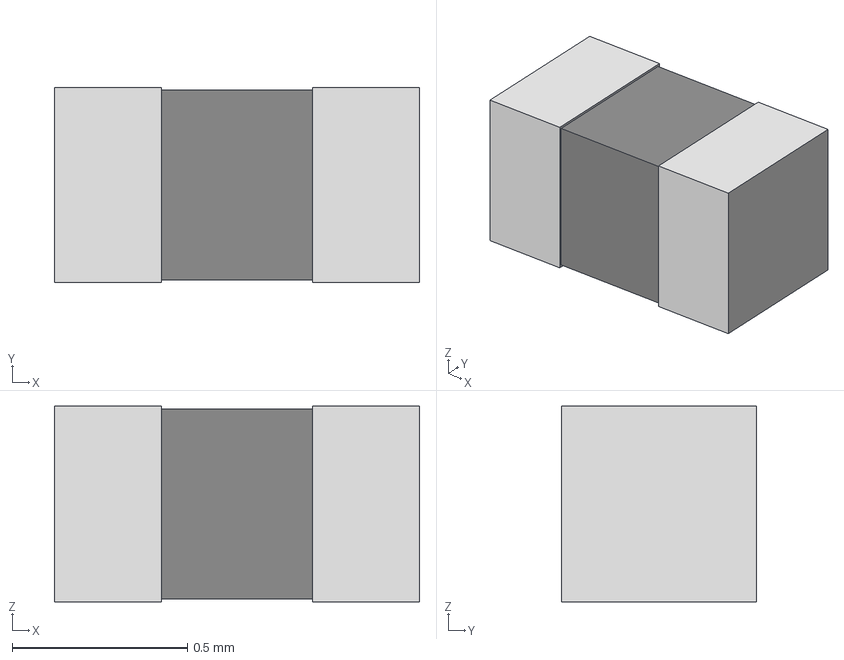
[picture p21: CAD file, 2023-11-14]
hardware/models/CC0402KR.step
1.04 x 0.558 x 0.559 mm

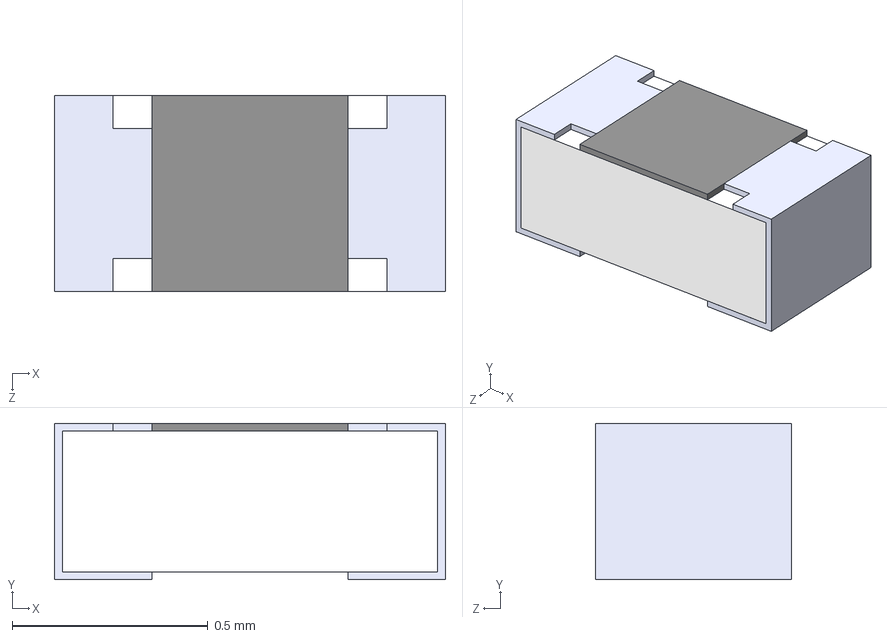
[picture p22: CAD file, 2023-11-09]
hardware/models/RC0402FR.step
1 x 0.4 x 0.5 mm

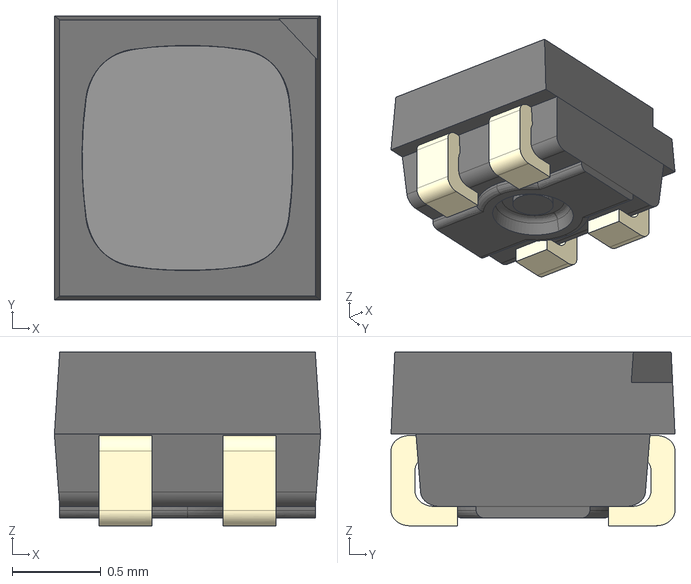
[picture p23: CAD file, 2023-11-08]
hardware/models/RS-1515MBAM.STEP
1.50 x 1.60 x 0.978 mm

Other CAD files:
hardware/models/RS-1515MBAM.ipt

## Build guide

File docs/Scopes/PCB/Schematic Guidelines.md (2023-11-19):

#5e5ce6/projects 

# Schematic Guidelines

- Label every net
- Use net ties
- Avoid 4-way junctions
- Annotate component reference designators by sheet number

## Symbols

- $100\,\text{mil}$ pin length

| Field | Example |
| --- | --- |
| Design Item ID | `RS-1515MBAM_SMT_PLCC4_0606` |
| Designator | `D?` |
| Comment | RS-1515MBAM |
| Description | PLCC4 SMT common anode RGB LED |

- Use `~` for active `LOW` pins

### Parameters

- Manufacturer
- Manufacturer Part Number
- Supplier
- Supplier Part Number
- Package
- Height (Max)

- Value

### Links

- Datasheet
- Supplier Link

## Footprints

- Pin 1 marker of $0.2\,\text{mm}$ width, $0.1\,\text{mm}$ radius
- Centred with pin & offset by nearest grid to $0.75\,\text{mm}$

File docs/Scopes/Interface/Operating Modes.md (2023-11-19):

#5e5ce6/projects 

# Operating Modes

- How is the user expected to select each mode/algorithm?
	- Have 'mode' LEDs that indicate the current mode?
	- Or display on the main matrix instead of the logo?

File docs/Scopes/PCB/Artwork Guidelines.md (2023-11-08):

#5e5ce6/projects 

# Artwork Guidelines

## Via Sizes

| Size | Pad | Drill |
| --- | --- | --- |
| Large  | $0.7\,\text{mm}$ | $0.3\,\text{mm}$  |
| Medium | $0.6\,\text{mm}$ | $0.25\,\text{mm}$ |
| Small  | $0.5\,\text{mm}$ | $0.2\,\text{mm}$  |

> [!warning] JLC Capabilities
> 1 & 2 Layer PCB: 0.3mm(hole size) / 0.5mm(diameter)

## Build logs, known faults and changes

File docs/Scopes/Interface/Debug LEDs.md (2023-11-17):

#5e5ce6/projects 

# Debug LEDs

- Want some collection of LEDs to aid in debugging/act as status indicators

- At a minimum, I will want:
	1. [[Scopes/Power/Power Indicator|Power LED]]
	2. [[Heartbeat LED]]
	3. [[Scopes/Interface/Status LED]] (maybe with colour?)
	4. [[Scopes/Interface/TX and RX LEDs]]

> [!question]
> How many debug/status LEDs do I *really* need?

- How do I plan on driving these?
	- Ideally I want these to be as simple as possible (ie directly to a GPIO, rather than through even an IO expander like a shift register)
	- This is to make debugging as easy as possible/as informative as possible—the LED will come on as soon as I toggle the GPIO
	- This is the advantage of dedicated debug/status LEDs, rather than using some subset of the [[display]]
	- Perhaps I can use the left-over bits in the [[Shift Registers|shift registers]]/[[LED drivers]]?
	- Maybe have some direct-debug LEDs/test points, and some more 'complex' full-colour LEDs routed through the spare bits in the [[Layout Design|display layout]]?
	- Regarding using spare bits in the [[Shift Registers|shift registers]]—this would not work with my preferred direct-chaining approach, as I am assuming that only a single row (and hence a single output across all shift registers) is active at any given time—using one of the unused bits for a status LED would not work.
	- I *could* potentially use the 5 unused output groups in my [[LED Drivers|LED drivers]] however, and leave the common anodes permanently tied to $V_\text{LED}$—this is fine, as I would not be multiplexing the status LED. This would only incur extra firmware/routing complexity, but could be considered.

- Do I want them to be single-colour, or RGB?
	- If they are RGB, I can reuse the same [[Discrete Non-Addressable RGB LEDs|BOM component]] as for my matrix—part consolidation & order quantity advantages
	- But, if they are RGB, then they will require more data lines (if I want a simple drive method)
	- I will also need individual current-limiting resistors, and I will only be able to produce the few colour permutations of pure R/G/B (unless I use PWM)
	- Alternatively, I can use addressable LEDs for my status LEDs?
	- If I use a single-colour LED, I only require a single GPIO pin
	- But I will need to have a whole extra part number

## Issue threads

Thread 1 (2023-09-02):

Determine project scope

JamesNZL, 2023-09-02:
- What features?
- What components?
- What should it be able to do?

JamesNZL, 2023-09-02:
LED matrix? or LCD/OLED/other display?

JamesNZL, 2023-09-24:
Scheduling algorithms?

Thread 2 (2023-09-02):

Decide on microcontroller

JamesNZL, 2023-09-02:
Perhaps this is a good opportunity to finally use an ESP32? Would allow me to quickly implement Bluetooth/WiFi connectivity without needing separate hardware

Or should I use a PSoC for the programmable analogue/digital?

JamesNZL, 2023-09-11:
Rust?

JamesNZL, 2023-11-19:
Have selected the [`STM32U575CIT6Q`](https://www.digikey.co.nz/en/products/detail/stmicroelectronics/STM32U575CIT6Q/18085454).

Closed 2023-11-19.

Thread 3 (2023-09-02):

Decide on display

JamesNZL, 2023-09-02:
Need to investigate operating voltages/data lines/current draw of a custom LED matrix, LCD, OLED display, etc

JamesNZL, 2023-09-04:
relevant
https://reddit.com/r/AskElectronics/s/6WX6J0120I

JamesNZL, 2023-09-04:
https://forum.arduino.cc/t/circuit-design-for-large-led-matrix/73433/2

JamesNZL, 2023-09-04:
Could possibly use a power bank?

JamesNZL, 2023-09-09:
https://youtu.be/H4OuxIwLgHw?si=GDOAzP9UEr0B6wy5

JamesNZL, 2023-09-10:
How can I do brightness control? Change the duty cycle of the period that I pull the cathode of each LED low?

JamesNZL, 2023-09-27:
https://www.instructables.com/RGB-LED-Matrix-1/

JamesNZL, 2023-09-30:
I want the matrix to have at least 20x15 leds

JamesNZL, 2023-11-10:
Can I tie the shift register clock to the LED driver latch?

Closed 2023-11-07.

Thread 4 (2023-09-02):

Design power switch circuit

JamesNZL, 2023-09-02:
Design the auto-shutdown implementation.

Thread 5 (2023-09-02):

Design power supply system

JamesNZL, 2023-09-02:
How am I going to get the required voltage to drive my display? A boost converter can only do so much—especially if I require high current draw

JamesNZL, 2023-09-02:
Must gave reverse polarity protection

JamesNZL, 2023-09-09:
https://github.com/isaac879/USB-Type-C-PD-Trigger-Board

https://reddit.com/r/electronics/s/c8nmdL8eed

JamesNZL, 2023-09-17:
https://youtu.be/OwAZqJ4wpJg?si=Gc3nOnLkX0mQ1vrt

(incl RGB LED)

JamesNZL, 2023-11-17:
https://electronics.stackexchange.com/questions/649227/implementing-usb-c-pd-phy-directly-into-micro-controller

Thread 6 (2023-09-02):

Design user interface

JamesNZL, 2023-09-02:
How is the user expected to select each mode/algorithm?

JamesNZL, 2023-10-05:
Clock speed LED—main loop

JamesNZL, 2023-10-05:
WiFi/Bluetooth—some software application to connect to the display? & set target coordinates etc?

JamesNZL, 2023-10-06:
Change display brightness

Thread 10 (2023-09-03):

Create PCB test board

JamesNZL, 2023-09-03:
I want to create a test board to test different manufacturer's solder mask colours/silkscreen quality/surface finish/etc

JamesNZL, 2023-09-04:
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

JamesNZL, 2023-09-05:
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

Closed 2023-09-04.

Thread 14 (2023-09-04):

Increase copper pullback

JamesNZL, 2023-09-04:
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

Should increase the amount of pullback on polygon pours from the board edge for the real board.

Closed 2023-09-10.

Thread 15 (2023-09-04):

Improve visual alignment of AV logomark

JamesNZL, 2023-09-04:
The outer horizontal edges of the AV logomark should be slightly expanded, as they currently appear too small.

Closed 2023-09-04.

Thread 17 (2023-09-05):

Animate logo

JamesNZL, 2023-09-05:
Use https://svgartista.net/ to animate the logo 😀

JamesNZL, 2023-09-05:
> [!IMPORTANT]
> Need to convert clipping path logo to strokes & fills

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

JamesNZL, 2023-09-05:
> [!NOTE]
> `transitions` don't appear to work, must use `animations`

JamesNZL, 2023-09-05:
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
https://jakearchibald.github.io/svgomg/

With SVGOMG, to prevent import errors, need to change the defaults of:
- [ ] Remove unknowns & defaults
- [ ] Remove hidden elements
- [ ] Round/rewrite paths

JamesNZL, 2023-09-05:
No real point optimising without removing hidden elements... maybe just skip optimising animated

JamesNZL, 2023-09-05:
(should be optimising before animating, anyway)

JamesNZL, 2023-09-05:
- Create simplified `logo-paths` file from the full logo file, which skips the outline stroke/compound path steps
- Optimise with [`SVGOMG`](https://jakearchibald.github.io/svgomg/)
- Import to [`SVG Artista`](https://svgartista.net/), with below settings
  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
- Copy markup and save as `logo-animated`
- Manually insert `<g>` groups from `logo-min`, and add the CSS transitions to fade in/out from animated to full gradient

JamesNZL, 2023-09-06:
New settings:
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

JamesNZL, 2023-09-06:
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

Closed 2023-09-05.

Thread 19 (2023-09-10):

Simulate hardware design

JamesNZL, 2023-09-10:
Use LTspice to simulate the hardware design.

JamesNZL, 2023-10-05:
Use pulse trains to simulate multiplexing, test source current etc

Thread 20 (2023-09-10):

Create hardware schematic

JamesNZL, 2023-09-10:
Complete the hardware schematic capture in Altium.

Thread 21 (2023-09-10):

Complete PCB artwork

JamesNZL, 2023-09-10:
Use the completed schematic in #20 to create the PCB artwork.

JamesNZL, 2023-09-11:
For the PCB thickness, I definitely want to be on the thicker end—at least 1.6mm

JamesNZL, 2023-09-17:
Rubber feet on bottom; want USB connectors on both long and short sides—desk and handheld usage

JamesNZL, 2023-09-25:
> For the PCB thickness, I definitely want to be on the thicker end—at least 1.6mm

Board will need to be 1.6mm to fit the rubber bumpers I've parted.

JamesNZL, 2023-10-31:
https://www.samtec.com/picturesearch/

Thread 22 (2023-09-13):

Use Altium ASCII files

JamesNZL, 2023-09-13:
Altium actually supports `.SchDoc` and `.PcbDoc` files to be saved in an equivalent ASCII format—this is the format that most other tools will expect for import.

Should use these file formats instead of the default binary format to better adhere to OSHW principles (& keep this project accessible after my Altium licence expires).

Closed 2023-09-13.

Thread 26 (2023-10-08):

Override `table` styling in docs

pumbas600, 2023-10-08:
The tables in the docs have the `border-collapse: separate;` style applied to `table` elements, which causes the double border effect seen below.

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

Using `border-collapse: collapse;` will prevent this effect :)

JamesNZL, 2023-10-08:
thanks ❤️

JamesNZL, 2023-10-08:
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

https://docs.jamesnzl.xyz/algovision

:)))

Closed 2023-10-08.

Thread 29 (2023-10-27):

Implement watchdog timer

JamesNZL, 2023-10-27:
Add a watchdog timer to reset on system hangs.

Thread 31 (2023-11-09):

Add ambient light sensor

JamesNZL, 2023-11-09:
Automatically adjust brightness based on ambient lighting conditions.

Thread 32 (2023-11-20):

Use STM32CubeMX to generate peripheral configuration code

JamesNZL, 2023-11-20:

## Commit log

2023-09-03 feat(pcb): :tada: create test board project (#10)
    [Test_Board.PrjPcb]
2023-09-04 feat(pcb): :sparkles: define test board shape (#10)
    [Test_Board.PcbDoc]
2023-09-04 feat(pcb): :sparkles: add silk tests (#10)
    [Test_Board.PcbDoc]
2023-09-04 feat(pcb): :sparkles: place logos on top layer (#10)
    [Test_Board.PcbDoc]
2023-09-04 feat(pcb): :sparkles: place logo on bottom solder (#10)
    [Test_Board.PcbDoc]
2023-09-04 chore(pcb): :package: export test board gerbers (#10)
    [Test_Board.GBL, Test_Board.GBO, Test_Board.GBS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]
2023-09-04 chore(pcb): :wrench: save test board project (#10)
    [Test_Board.PrjPcb]
2023-09-05 feat(pcb): :alien: update test board with latest logo (#10)
    [Test_Board.GBL, Test_Board.GBO, Test_Board.GBS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]
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2023-09-10 feat(hardware): :sparkles: increase copper pullback (#14)
    [Test_Board.PcbDoc]
2023-09-10 chore(hardware): :package: update test board gerbers (#14)
    [Test_Board.GBL, Test_Board.GBO, Test_Board.GBS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]
2023-09-10 feat(hardware): :tada: create main board project (#20, #21)
    [Main_Board.PrjPcb]
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2023-09-10 feat(hardware): :sparkles: create main board schematic (#20)
    [Main_Board.PrjPcb, Main_Board.SchDoc]
2023-09-10 chore(hardware): :wrench: configure default text font (#20)
    [Main_Board.SchDoc]
2023-09-10 feat(hardware): :sparkles: decrease size of project name (#20)
    [Main_Board.SchDoc]
2023-09-13 refactor(pcb): :globe_with_meridians: save altium files in ascii formats (#22)
    [Main_Board.SchDoc, Test_Board.PcbDoc]
2023-09-14 chore(pcb): :package: export test board drills (#14)
    [Test_Board.PcbDoc, Test_Board.PrjPcb]
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2023-10-04 chore: :page_facing_up: licence full karbon font (#8)
    [Main_Board.SchDoc, Test_Board.PcbDoc]
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2023-10-27 refactor(pcb): :technologist: create project parameter for revision key (#30)
    [Main_Board.PrjPcb, Power.SchDoc]
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2023-11-07 feat(pcb): :sparkles: create display schematic (#20)
    [Display.SchDoc, Main_Board.PrjPcb]
2023-11-08 feat(pcb): :sparkles: create net tie component (#20)
    [Main_Board.PrjPcb, algovision.PcbLib, algovision.SchLib]
2023-11-08 feat(pcb): :sparkles: add `rs-1515mbam` component (#20)
    [algovision.PcbLib, algovision.SchLib]
2023-11-08 feat(pcb): :sparkles: add `rs-1515mbam` model (#20)
    [RS-1515MBAM.STEP, RS-1515MBAM.ipt, algovision.PcbLib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]
2023-11-08 feat(pcb): :sparkles: add `sn74hcs594pwr` component (#20)
    [Display.SchDoc, algovision.PcbLib, algovision.SchLib]
2023-11-08 feat(pcb): :sparkles: add `tlc5951dap` component (#20)
    [algovision.PcbLib, algovision.SchLib]
2023-11-08 feat(pcb): :sparkles: add `sil2301-tp` component (#20)
    [Main_Board.PrjPcb, algovision.PcbLib, algovision.SchLib]
2023-11-09 feat(pcb): :sparkles: save schematic primitive default preferences (#20)
    [algovision.PcbLib, algovision.SchLib]
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2023-11-09 feat(pcb): :sparkles: add `rc0402fr-07100kl` component (#20)
    [RC0402FR.step, algovision.PcbLib, algovision.SchLib]
2023-11-09 feat(pcb): :sparkles: add `rc0402fr-071kl` component (#20)
    [algovision.PcbLib, algovision.SchLib]
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2023-11-09 feat(pcb): :sparkles: begin matrix schematic (#20)
    [Display.SchDoc, algovision.SchLib]
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2023-11-10 feat(pcb): :sparkles: move matrix to own sheet (#20)
    [Main_Board.PrjPcb, Power.SchDoc, algovision.SchLib]
2023-11-10 feat(pcb): :sparkles: add current amplifiers (#20)
    [Display.SchDoc]
2023-11-10 fix(pcb): :rotating_light: fix net identifier scope (#20)
    [Display.SchDoc, Main_Board.PrjPcb]
2023-11-10 refactor(pcb): :art: refactor current amplifiers (#20)
    [Display.SchDoc]
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2023-11-10 feat(pcb): :sparkles: add led driver output nets (#20)
    [Display.SchDoc]
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2023-11-11 feat(pcb): :sparkles: change amplifier gate pull-up resistors (#20)
    [Display.SchDoc]
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2023-11-14 feat(pcb): :sparkles: add shift register decoupling capacitors (#20)
    [Display.SchDoc]
2023-11-14 feat(pcb): :sparkles: add shift register clear pull-up resistors (#20)
    [Display.SchDoc]
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2023-11-14 feat(pcb): :sparkles: add net ties for shift register serial data wires (#20)
    [Display.SchDoc]
2023-11-14 feat(pcb): :sparkles: chain remaining led driver inputs (#20)
    [Display.SchDoc]
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2023-11-17 feat(pcb): :sparkles: tie greyscale reference clocks together (#20)
    [Display.SchDoc]
2023-11-17 refactor(pcb): :bulb: add notes to display sheet (#20)
    [Display.SchDoc]
2023-11-18 refactor(pcb): :bulb: update row multiplexing bounding block title (#20)
    [Display.SchDoc]
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2023-11-18 refactor(pcb): :bulb: add todo note for `gsck` crystal (#20)
    [Display.SchDoc]
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2023-11-19 docs: :truck: move current sensing note to correct folder
2023-11-19 fix(pcb): :bug: add led driver vcc power port (#20)
    [Display.SchDoc]
2023-11-19 docs: :memo: identify problem with current amplifiers if mcu is not ttl (#3)
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2023-11-19 refactor(pcb): :art: hide gnd power port name label (#20)
    [Display.SchDoc]
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2023-11-19 refactor(pcb): :art: rename supply nets with `+` prefix (#20)
    [Display.SchDoc]
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2023-11-20 docs: :memo: add notes on current amplifier problem (#3)
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2023-11-20 refactor(pcb): :art: change order of `pb3` pin alternate functions (#20)
    [Micro.SchDoc, algovision.SchLib]
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2023-11-21 feat(pcb): :sparkles: add generic ferrite bead component (#20)
    [algovision.SchLib]
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2023-11-21 feat(pcb): :sparkles: add variant for `dnp` components (#20)
    [Main_Board.PrjPcb, Micro.SchDoc, Power.SchDoc]
